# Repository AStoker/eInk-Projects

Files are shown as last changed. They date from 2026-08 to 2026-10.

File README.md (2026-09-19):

# eInk Projects

A 4.2" three-colour e-paper panel in a printed desk frame that shows today's
agenda, your photos, or a picture generated overnight.

| Where | What |
|---|---|
| [stand-4.2in/](stand-4.2in/) | The printed frame, the wiring, the power budget |
| [daily-dash/](daily-dash/) | ESPHome firmware for the panel |
| [eink-app/](eink-app/) | Home Assistant app that converts images for the panel |
| [IMAGE-PIPELINE.md](IMAGE-PIPELINE.md) | How a picture becomes ink: blob format, prompts, contracts |

This repo is also a **Home Assistant add-on repository** (`repository.yaml`),
so the app installs from the store rather than by copying files.

## Using it day to day

Everything is grouped under the **eInk Daily Dash** label in Home Assistant.

| Control | Does |
|---|---|
| `input_select.eink_daily_dash_mode` | **Dash** (agenda), **Photos**, or **AI** |
| `input_text.eink_daily_dash_theme` | Theme for the generated pictures — `fall`, `christmas`, blank for free choice |
| `input_boolean.eink_daily_dash_disable_deep_sleep` | Hold the panel awake so it can be flashed |
| `button…refresh_display` | Redraw now — only works while the panel is awake |
| `automation.eink_daily_dash_generate_ai_images` | The 3am job. Run manually to preview |

**To show your own photos:** drop them in `/media/eink/photos/` and switch the
mode to Photos. Subfolders are fine. The app picks them up within 20 seconds,
converts them, and the panel rotates one photo per wake. Nothing else to do —
no resizing, no naming convention, no restart.

**To change the generated pictures:** type a word into the theme box. That
night's set follows it.

## How the panel behaves

It wakes every 15 minutes, draws once, and sleeps — about 25 seconds awake,
because a full e-paper refresh takes 17 of them. Two consequences worth
knowing:

- **A button press only lands while it is awake.** Mode and theme changes take
  effect on the next wake, up to 15 minutes later. To make a change land now,
  turn the hold-awake toggle on first — then the panel is listening.
- **It only refreshes when the picture actually changed.** The panel asks the
  app for a short revision string first and skips the refresh if it matches.
  **Pressing Refresh Display overrides that**, as does changing the mode, so a
  deliberate request always redraws.

## Flashing

`daily-dash/example-device.yaml` is the device file for ESPHome Device Builder;
it pulls the firmware from this repo. See [daily-dash/](daily-dash/) for the
package layout and the two entry points.

The case has no opening for the driver board's USB-C, so **OTA is the only way
in once it is assembled**. Turn the hold-awake toggle on before flashing. A
cold boot also stays up for two minutes regardless, which is the way back in if
the toggle is unreachable.

## State of things

| Working | Not done |
|---|---|
| Agenda rendering, deep sleep, OTA window | Battery divider not fitted — GPIO 35 floats, HA shows ~0 V |
| Nightly generation, theming, photo drop | Low-voltage cutoff, deliberately, until the divider reads true |
| Blob format, converter, image server | The app has not yet run inside Home Assistant |

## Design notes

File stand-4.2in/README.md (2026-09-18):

# 4.2" e-Paper desk frame — minimal bezel, snap-out kickstand, battery inside

A slim desk frame for the **Waveshare 4.2inch e-Paper panel (B)** driven by the
**Waveshare e-Paper ESP32 Driver Board (Rev 3)**, with a LiPo and a power-path charger
inside, and a single kickstand leg on the back that folds flush and swings out onto a
positive mechanical stop. Portrait.

The panel is **bare glass and an FPC tail** — no PCB behind it. The tail leaves the centre of
the **RIGHT** side and makes a shallow S, out and up towards the **TOP**, before turning
inboard. It reaches the driver board's socket — but it has no slack, so it cannot survive the
cover being lifted off. A **Waveshare FPC adapter** is fitted as a service loop.

One parametric OpenSCAD file: `src/epaper_stand.scad`. Every dimension quoted here comes
out of it, and so does every drawing — `tools/mkdrawings.py` reads the model's own
parameter dump, so the sheets cannot drift from the STLs. **The renders are built from
`stl/*.stl` itself** (`tools/mkrenders.sh`), so what the pictures show is what the slicer
gets.

| | |
|---|---|
| Outer | 91.9 × 110.5 × 25.0 mm |
| Bezel | 13.45 mm short-axis sides, 11.55 mm long-axis ends |
| Panel white showing | 0.7 mm short axis, 1.3 mm long axis |
| Lean | 22.3°, 34.1 mm footprint |
| Interior | 81.6 × 92.5 × 21.0 mm, with 9 mm end walls |
| Fasteners | 4 × M2.5 countersunk into heat-set inserts, one near each corner |
| Print | 3 parts, ~112 g of filament; supports on the leg only |

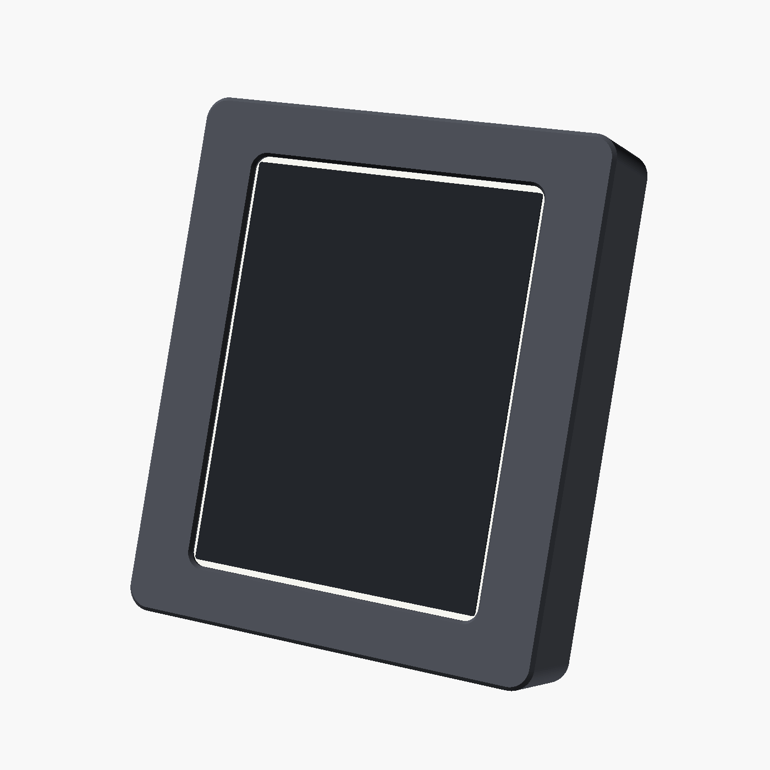
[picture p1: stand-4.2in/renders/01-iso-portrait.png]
Deployed
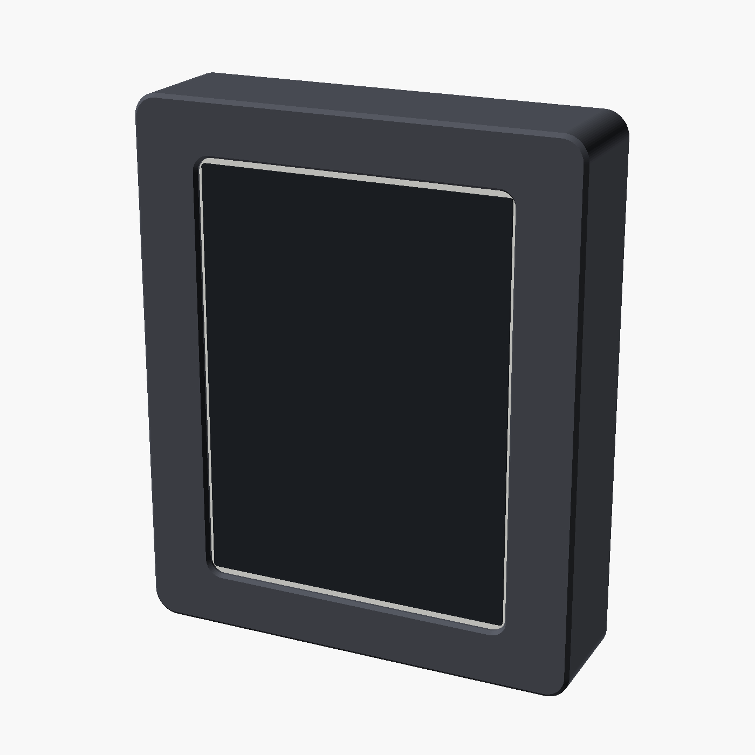
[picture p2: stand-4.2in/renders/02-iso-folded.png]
Folded
 

Sheet 1 — assembly and envelope

Open [`drawings/index.html`](drawings/index.html) for all eight sheets on one page,
[TODO.md](TODO.md) for what is still open, and [`fusion/README.md`](fusion/README.md) to
pick the model up in Autodesk Fusion.

---

## Names

Two dimensions got read as the wrong axis while this was being built, both times because
"width" and "height" swap over when the frame is turned. So: **never width/height for
anything belonging to the display.**

| Axis | Glass | Interior | Model | In portrait (the default) |
|---|---|---|---|---|
| **short axis** | 76 | 82.1 | X | horizontal |
| **long axis** | 90 | 80.9 | Z | vertical. **The ribbon leaves the glass on a long-axis edge, and runs along the long axis.** |
| **depth** | 1.05 | 21.0 | Y | 0 at the outer front face |

Depth is the axis that points *up* off the print bed, so "taller", "more room on top" and
"height off the glass" in slicer terms all mean **deeper** here.

### The four sides have names

Width/height are banned because they swap when the frame turns. So do "top" and "bottom"
unless you say which way up — so the datum is fixed once, here, and everything uses it:

**Hold the panel with the front face down, in portrait.** You are looking at the **rear
face**. Put 0,0 at the top-left, X increasing across, Y increasing down. Then:

| Side | Which edge | Length | Runs along |
|---|---|---|---|
| **TOP** | Y = 0, X sweeping across | 76 (glass) | the short axis |
| **BOTTOM** | Y = max, X sweeping across | 76 | the short axis |
| **LEFT** | X = 0, Y sweeping down | 90 | the long axis |
| **RIGHT** | X = max, Y sweeping down | 90 | the long axis — **the tail leaves this side** |

And the two faces are **front face** (the ink you look at) and **rear face** (the back, facing
you during assembly). Never "top face" for either.

### How those map into the model

The model does not use the build frame and is not going to be renamed, so here is the
mapping. It is worth reading once, because two separate bugs came out of getting it wrong:

| Build frame (front face down, 0,0 top-left) | Model |
|---|---|
| **TOP** | `+Z` end — `Z = 100.25` at the glass |
| **BOTTOM** | `−Z` end — `Z = 10.25` at the glass. **The kickstand folds down towards here**, foot tip at `Z = 3` |
| **LEFT** | `+X` side |
| **RIGHT** | `−X` side — the ribbon relief reaches `x = −44.95` |
| **front face** | `Y = 0` |
| **rear face** | `Y = 25` |
| X increasing (left → right) | `−X` direction |
| Y increasing (top → bottom) | `−Z` direction |

Two sign flips to keep hold of:

- **Build-Y and model-Z run opposite ways.** "18 mm down from the top" is `Z = 100.25 − 18`,
  not `Z = 18`.
- **Build-X and model-X also run opposite ways**, because looking at the *rear* face reverses
  the short axis. Derive it if you doubt it: looking along `−Y` with `+Z` up gives a view-right
  of `cross((0,−1,0),(0,0,1)) = (−1,0,0)`. That is why RIGHT is `−X`, and why the relief being
  at `x = −44.95` is correct rather than mirrored.

What fixes `−Z` as the BOTTOM, independently, is the kickstand: it pivots at `Z = 58` and its
foot folds *down* to `Z = 3`, and a stand's foot is at the bottom.

### The ribbon route

Front face down, portrait, so you are looking at the **rear face**. The tail leaves the
**CENTRE of the RIGHT side** — not an end — and makes a shallow S:

| Leg | Direction | Size | Parameter |
|---|---|---|---|
| 1 | straight out from the glass edge | 4 mm | `rib_out` |
| 2 | 90° turn towards the **TOP**, running parallel to the RIGHT edge | 9 mm wide × 20 mm long | `rib_band`, `rib_run` |
| 3 | 90° turn **away from the RIGHT side** — inboard, across the rear face | 10 mm | `rib_leg3` |

Leg 2 is the whole reason the relief is a slot rather than a local pocket at the exit: the
ribbon spends 20 mm travelling *parallel* to the RIGHT edge before it turns inboard. Leg 2 is
9 mm wide but only reaches 4 mm outboard of the glass — the other 5 mm of its width lies
*behind* the glass, which is open interior, so the frame only has to clear 4 mm.

The three relief sizes are deliberately *not* called width/height/depth:

| | Parameter | Now | Meaning |
|---|---|---|---|
| **out** | `rib_clr` | 3.0 | outboard from the pocket edge, along the short axis |
| **deep** | `rib_dep` | 3.0 | past the glass back face, along depth — so the fold has somewhere to go |
| **long** | `rib_w` | 49.0 | along the RIGHT edge, on the long axis |

**`rib_w` and `rib_off` are derived from the route now, not typed in.** `rib_w` is
`rib_run + rib_band + 2 × rib_marg` and `rib_off` puts the slot's near edge half a band below
the exit, so the slot straddles the exit and covers the run to the TOP. They come out at 33
long, **30.5 up from the BOTTOM, 10.5 short of the TOP** — and they cannot drift from the
route any more, which is how they went wrong twice:

- `rib_off = 15` put the slot at the **BOTTOM**, under a source comment insisting the model's
  −Z was the top and warning against "fixing" it. It was the reversed reading it warned about.
- `rib_off = 35` then put the slot 15 short of the **TOP**, from reading "the ribbon is towards
  the top" as the exit position. The exit is at the **centre**; it is the *run* that goes
  towards the top. It is 30.5 now, and derived rather than typed.

**One clearance is 0.25 mm short.** Leg 1 needs 4 mm out from the glass edge; the relief gives
3.75 (`rib_clr` 3.0 from the pocket edge, plus 0.75 of pocket clearance). `rib_clr = 3.25`
would fix it and grows the frame 0.5 mm on the short axis. The stand no longer rides on the
frame's width, so the stance does not move with it, but the frame does. The echo prints the
shortfall on every run.

### The tail reaches the driver — but it cannot cross the split

The driver board faces **down**, so its socket edge is the one nearest the display, and the
tail can meet it. Leg 3 runs **10 mm** inboard, ending between x −35.2 and −26.2.

Which way round the board is mounted decides whether it fits:

| Socket 12.5 mm from… | Board spans | |
|---|---|---|
| the **BOTTOM** end | z 62.75 … 111.0 | overruns the interior top by 9.5 mm |
| the **TOP** end — hangs downward from the socket | z 39.5 … 87.75 | **fits** (`fpc_end = "top"`) |

So a direct plug-in works geometrically. **The reason it still is not enough is service.**

The glass is on the **frame**. The driver is on the **cover**. Anything joining them crosses
the split, and the panel's tail cannot:

| | |
|---|---|
| Tail length | 18 mm, with no slack designed in |
| What its 180° fold gives back when it straightens | (π−2) × `rib_dep` = **3.4 mm** |
| Lift needed to get a fingernail on a ZIF lever | ~25 mm |
| Shortfall | **21.6 mm** |

Lift the cover and you are pulling on the glass. So the **adapter is a service loop, not a
reach fix**: the short tail plugs into it on the panel side, and a longer FPC crosses the
split with enough slack to open the case.

### Where the service loop goes

Two placements were costed and both fail, which is worth recording because the answer is
neither of them:

- **In front of the driver.** Stacks 5 mm onto 16 against the 17.45 mm the driver column has —
  3.55 short, and the driver's own USB-C shell and WROOM module already take most of what is
  left there. It would cost `depth` 25 → 28.55, or low-profile headers (`hdr_h` 8.5 → 5.5 buys
  back 3.0).
- **On the carrier board.** Driver 48.25 + adapter 32 = 80.25 against 70, and overhanging fails
  too because the adapter's corner holes are 28 apart, so the far pair lands off the board.

Mounting the driver on the **frame** instead, so nothing crosses the split at all, does not
work either: the glass drops in through the interior and needs the full 90 mm clear, so
anything standing off the frame's ledge blocks it — the same reason there are no corner posts.

**The adapter is taped to the back of the glass.** That is what makes it fit, and it is also
the right side of the split — taped to the glass it stays with the **frame**, so the panel's
short stiff tail never crosses the joint and only the long FPC does.

| | |
|---|---|
| Outline | 18 × 32 × **5 mm** (depth with both connectors, confirmed) |
| Where | against the glass's back face, x −40.45 … −22.45, z 65.75 … 97.75 |
| Depth there | glass back 2.65 to the carrier's face 18.5 = **15.85 mm**, so it clears by 10.85 |
| Clear of the driver's parts by | 2.0 mm (`adapt_gap`; 1.0 still caught them by 0.2) |
| Leg 3 | turns at z 75.25 and runs **10 mm** inboard, ending between x −35.2 and −26.2 — **lands on the adapter** |
| Holding force | 18 × 32 = 5.8 cm² of foam tape ≈ 46 N in shear against a 0.02 N part |

It overlaps the carrier by 18.75 mm **in plan view**, and that is not a clash — they are 10.85 mm
apart in depth. Reading that plan-view overlap as a conflict is what made the adapter look
homeless for so long, and it was never real.

Two things moved to make room, both small: the **top glass-retention rib** shifted toward +X
(`pad_off1` 12.0 → 7.8, so it spans x −21.0 … −1.0 instead of −25.2 … −5.2, still well inside
the glass's dead border), and the adapter sits 2 mm above the driver's tall parts.

The one real risk is **peel, not shear**: a 24-pin FPC pushing perpendicular can lift a corner.
Route the tail so its spring-back loads the tape in shear, and use foam rather than a thin
film so it can absorb the bend.

**Oversize is free here.** The hollow is only ever a problem when it is too *small*, so
`rib_marg` is set generously (10) rather than to the route. The hollow is **49 mm** — 14.5 mm
below the exit and 34.5 above — which covers leg 2 running anywhere from nothing to 34 mm, and
so covers both the 18 mm and the 24 mm readings of the tail length. That takes the
disagreement between them off the critical path.

**What caps its length is the corner screws, not the route.** The inserts at z 14.5 and 96
reach x −38.65, which overlaps the hollow's x −44.95 … −41.95 by 3.3 mm — so the hollow has to
stop short of them. It ends at z 89.75 against a bore starting at 94.2: **4.45 mm of headroom.**
The other cost of length is the 1 mm outer wall outboard of it, now 49 mm long. The
`RIBBON HOLLOW HEADROOM` echo prints both on every run, so it cannot quietly grow into a screw.

**Leg 3 only has to land on the adapter, not hit a socket.** The tail folds over onto it, and
the cable on from the adapter to the driver is routed by hand — so nothing downstream of the
adapter is constrained by geometry. That is what takes the whole layout off the critical path.

**One measurement still disagrees:** the route needs at least 4 + 20 = **24 mm** of developed
tail before leg 3 starts, against the **18 mm** measured flat. Whichever is right decides
whether leg 2 really runs 20 mm, and `rib_w` / `rib_off` are derived from it — so the ribbon
hollow moves with it.

### The three nested recesses

Front to back. Not interchangeable, and each has its own clearances:

| Name | What it holds | Size | Parameters |
|---|---|---|---|
| **window** | nothing — it's the through-opening the ink is seen through | 65.0 × 87.4 | `win_*` |
| **glass pocket** | the glass, in a shallow step | 77.5 × 91.5 × 1.26 | `pan_*` |
| **interior** | the electronics — driver board, cell, charger | 82.1 × 80.9 | `cav_*` |

**The interior is sized by two things: the electronics, and the glass getting in.** The
glass has no way into its pocket except from the back, through the interior — the front lip
is smaller than the glass. So the interior opening has to clear the glass on every side:

```
GLASS GOES IN: interior x -42.45 to 39.15, z 9 to 101.5
             | glass    x -42.45 to 36.05, z 10.25 to 100.25
             -> clears on every side, drops straight in
```

Note that it checks **extents, not sizes**. The glass is offset 3.2 mm to centre the ink, so
an interior that is wide *enough* can still be in the wrong place — comparing sizes left it
0.4 mm short on the −X side, which is a glass that does not go in.

### Why there are no screw posts inside the interior

Corner posts would be the obvious way to get four corner screws without growing the frame,
and they do not work. A post at each corner leaves a 74.5 mm gap for a 90 mm glass, so the
glass would have to go in at an angle — and the arithmetic says it cannot:

| To shorten the glass's span to | you must tilt | which stands it |
|---|---|---|
| 85 mm | 19.2° | 29.6 mm tall |
| 83 mm | 22.7° | 34.8 mm tall |
| 81 mm | 25.8° | 39.2 mm tall |

The interior is **20.9 mm deep**. The glass is flat long before its far end is low enough to
clear anything, and flat it needs a post-free path the full 90 mm. Working it the other way:
with 9 mm posts the glass is blocked by 5.9–7.0 mm no matter how deep the posts start, and
only a **3 mm** post ever clears — which will not hold an insert.

So the screws go in the end walls, and the end wall has to be thick enough to take one:
rear chamfer + margin + head + margin. That is what sets the frame's long axis now.

| Insert | Head | End wall | Frame length | End bezel |
|---|---|---|---|---|
| M2 | 4.0 | 8.0 | 108.5 | 10.55 |
| **M2.5** | **5.0** | **9.0** | **110.5** | **11.55** |
| M3 | 6.0 | 10.0 | 112.5 | 12.55 |

M2.5 is the default: 2.1 mm of extra length against today, and four screws that go where
they are wanted. `insert_size` moves the whole frame with it.

### Vocabulary

- **bezel** — the visible plastic between the window edge and the outer edge (13.45 on the
  short-axis sides, 10.5 on the long-axis ends). Never the pocket. Also not a *bevel* — a
  bevel is an angled edge, which here is a **chamfer** (`front_chf`, `win_chf`, `rear_chf`).
- **clearance** / **margin** — the gap between a part and the recess holding it. Always
  quoted as the **total across an axis**, not per side: "margin 1.5 on the short axis" is
  0.75 a side.
- **relief** — material taken away at a **corner**, so a sharp-cornered part can seat in a
  printed corner that carries a nozzle fillet. Always centred *on* the corner; that is the
  function, so it cannot be moved inboard. One is fitted: **pocket relief** (`pan_rel` = 1.4,
  at the glass pocket corners). Because it is centred on the corner it bulges 1.4 mm
  *outboard* of the pocket — further out than the interior reaches on three sides — so the
  interior wall used to **overhang it by 0.9 mm**. The same four circles are now carried up
  through the wall as well (see `cavity()`), so the opening holds at x −43.32 from the pocket
  right through to the rear face instead of stepping back in. It costs nothing dimensionally:
  2.63 mm of wall is still left outboard of the worst corner.
- **ribbon relief** — the slot described above.
- **white show** — `white_show_short` / `white_show_long`, the strip of the panel's own white
  border left visible inside the window on purpose. **One per axis** (0.7 short, 1.3 long),
  because the window is specified on the short axis and one shared value cannot do both.
- **parts** — **frame** (front shell), **cover** (back), **leg** (kickstand), and the
  **bezel test tile** (front-face-only print for checking fit).
- **tape pad** — `tape_*`, a shallow recess in the **ledge behind the glass** where tape holds
  the glass down from the rear. Two of them, one at each long-axis end. Not visible from the
  front.

### How the glass is held

A printed 91.0 pocket measured short on the long axis, so the pocket is **77.5 × 91.5** —
1.5 mm of total margin on *both* axes, sized for print variance rather than for a press
fit. The front lip stops it coming forward. Behind it the interior is open, because it has
to be, so something has to press it back against that lip: **two ribs on the cover**, one at
each long-axis end, over the glass's dead border — 36 mm and 20 mm wide × 3.5 mm, standing
the full 21 mm from the cover face to just behind the glass. Foam tape on their faces takes
up the tolerance stack.

The top rib is the short one because the charger runs up that side of the interior.

---

## Power

One cell, one charger, one conversion. USB-C in at the back face, the charger's power-path
output straight to the driver board's 5V pin, which Waveshare specify as a **3.6–5.5 V
input** — a 1S cell drives it directly.

Sheet 8 — power wiring

- **Adafruit bq25185** (#6091, $6.95): USB-C in, JST battery, JST load out regulated to
  ≤4.5 V, real power path so the board runs from USB while the cell charges instead of
  cycling it. Charge current is a solder jumper — **set 1 A**, which is 0.5C for this cell.
  Adafruit's own two pages disagree on what it ships at (product page says 1 A, the pinout
  guide says 500 mA), so check the board.
- The board's 5V pin is an input only: no charge circuit, no battery connector, no charge
  LED. Running from a cell and refilling that cell are two separate jobs, which is why the
  charger is in the build.
- **Charge port is on the back face**, not the charger's own USB-C. A snap-in panel-mount
  pigtail with the 5.1 kΩ CC pulldowns sits in the back face at **x −5, z 92** — immediately
  left of the charger, so the two wires to its **VBUS** and **GND** pads run about 4 mm
  instead of crossing the whole interior. Charge only, no data — which is all this needs.
- **Battery divider:** two 100 kΩ from the cell to **GPIO 35**, wired as below. The
  firmware reads it on every wake and reports the voltage to Home Assistant.

### Wiring the battery sense

The ESP32 cannot read the cell directly — a full 1S pouch is 4.2 V and the ADC tops out
around 3.1 V — so the cell is halved by a divider first.

```
  cell +  (JST B+, red)
     |
    [R1] 100 kΩ
     |
     +-------------------> GPIO 35   (ADC1_CH7, the divider tap)
     |
    [R2] 100 kΩ
     |
  cell -  (JST B−, black, common with the driver board's GND)
```

Both resistors are 100 kΩ, so the tap sits at exactly half the cell: 4.2 V reads 2.10 V,
3.6 V reads 1.80 V. The firmware's `multiply: 2.0` filter puts it back. Equal resistors
are the whole trick — change one and change `batt_divider` in the YAML to match.

| Why this value | |
|---|---|
| **100 kΩ + 100 kΩ** | 200 kΩ across the cell draws 21 µA, about 1% of the board's 2 mA idle. Ten times smaller wastes real runtime; ten times larger and the ADC's own input impedance starts to pull the reading down |
| **GPIO 35** | ADC1. **ADC2 cannot be read at all while WiFi is on**, which rules out the entire 0/2/4/12–15/25–27 group. GPIO 35 is also input-only, so it can never be driven high into the divider by accident |
| **not GPIO 32/33** | Also ADC1 and equally valid, but they are the two RTC-capable pins the frame's button cutouts are waiting on — see the buttons section. GPIO 35 leaves both free |
| **not GPIO 34/36/39** | Fine electrically. GPIO 35 is simply the one the firmware is set to; change `batt_adc_pin` if the header layout makes another easier to reach |

Tie the divider's bottom leg to the **driver board's** ground, not just the cell's — the
ADC measures against the ESP32's own ground reference, and a divider referenced somewhere
else reads whatever the difference between them happens to be. They are the same net once
the cell is plugged in through the charger, so this is about which point you land the
wire on, not about adding a connection.

Nothing is fitted yet, so **GPIO 35 currently floats and Home Assistant shows a near-zero
voltage** — that is the reading for "not wired", not a flat cell.

Still to do once it is fitted: the low-voltage cutoff. The intent is that below ~3.6 V the
firmware calls `esp_deep_sleep_start()` with no timer and stays there — the board browns
out at 3.6 V on its own, but a brownout loop drags the cell down to its protection cut,
and deep discharge is what kills LiPo cells. That path is deliberately **not** in the
firmware yet: with no divider fitted the floating pin reads near zero, which looks
identical to a flat cell, and a board that sleeps with no wake source inside a sealed case
is unrecoverable. Wire the divider, confirm the voltage reads true, then add the cutoff.

### One opening in the whole assembly

The **charge port in the back plate is the only hole in the finished case.** The driver
board's own USB-C — which is for *flashing*, not power — used to sit against the top wall
behind a blind pocket. Now that the board is stood on the −X side to meet the ribbon, its
jack ends up in the middle of the interior instead, so there is nothing to cut and nothing
to seal: the pocket is skipped entirely and the top wall is solid material.

⚠ **Flash the ESP32 before final assembly**, and leave OTA working. With the port closed
there is no wired access to the driver board once the cover is on. Set `flash_port = true`
to cut the opening back through.

### Runtime

The driver board sets it: Waveshare rate it at `<2 mA` idle, and only with the **DIP switch
set so the USB-UART is unpowered** — left powered, a reviewer measured 10–13 mA in "deep
sleep". So: **switch on to program, off to run.** (On the Rev 3 schematic that chip is a
**CH343**, not the CP2102 quoted on the older product page; SW1 gates its supply from
VBUS.)

The same schematic shows **GPIO 4 driving an S8050 that gates the panel's supply rail**
(VDD5V → VDD5V′, feeding the EPD 3.3 V regulator). That is a real power saving — the panel
rail can be switched off in sleep — and it means **GPIO 4 is not free for anything else.**

At 2 mA and ~49 mAh/day, against the 3.6 V floor (which leaves about 85% of the cell's
2000 mAh usable), runtime is **roughly five weeks** — about 35 days on battery, ~41 days
standby, ~33 days with an hourly refresh. About 95% of that budget is the board sitting
idle; a few refreshes a day cost barely 1 mAh between them. Refresh as often as you like,
it is not what empties the cell.

`<2 mA` is a spec, not this board — put a meter in series with the battery lead and read
the real number. If there is a power LED, cutting it is often worth 1–2 mA on its own.

### The cell

A salvaged 1S pouch, **2000 mAh, 694449, 44 × 49 × 6.9 mm**, three wires, all three
checked on this pack:

| Wire | Is | Goes to |
|---|---|---|
| red | **positive** (verified against black) | JST B+ |
| black | **negative** | JST B− |
| yellow | the other leg of a **10 kΩ NTC** (measured yellow→black at room temperature; its common leg is tied to black) | the charger's **TH** pad |

So the thermistor gets used: **cut the TH jumper** on the #6091 (it ships jumpered, which
disables the function) and wire yellow to the pad. The charger then refuses to charge
outside roughly 0–45 °C instead of trusting a salvaged pouch to behave.

The pack also carries **its own protection PCB** under the tape at the tab end, so it has
overcurrent, overdischarge and short protection independent of the charger.

## Buttons

Not fitted, but the frame is ready. The display uses **GPIO 13 (CLK), 14 (DIN), 15 (CS),
25 (BUSY), 26 (RST), 27 (DC)**; everything else on the headers is yours. For buttons that
also wake the ESP32 from deep sleep you need RTC-capable pins — **GPIO 32/33 are the
cleanest** if the headers bring them out. **Not GPIO 4** — on this board it gates the
panel's supply rail. Keep off 0, 2, 12 and 15 as well: they are strapping pins, and a
button held at reset changes boot behaviour.

To add them later: set `btn_n = 3` in the SCAD file and re-export the frame. That cuts
three Ø4.2 plunger holes in the +X wall (9.4 mm thick, the only wall with real meat in
it), 12 mm apart, for switches mounted on a strip inside. There is no room for front
buttons — the bezel is 10.5 mm and the module's PCB is directly behind it.

---

## What goes where

Interior is 82.1 × 80.9 mm in two columns: the driver board against the −X wall — the wall
the ribbon arrives at — and the cell with the charger above it on the +X side.

Sheet 2 — internal layout

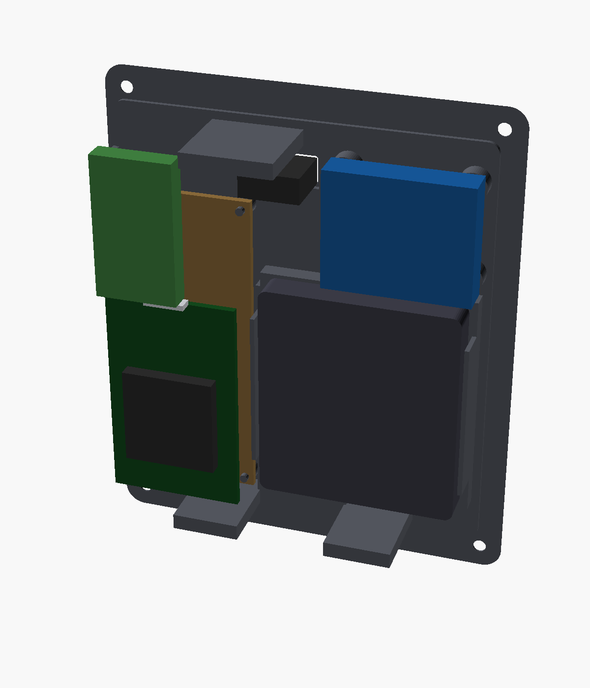
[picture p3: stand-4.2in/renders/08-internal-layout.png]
Boards and cell in the cover
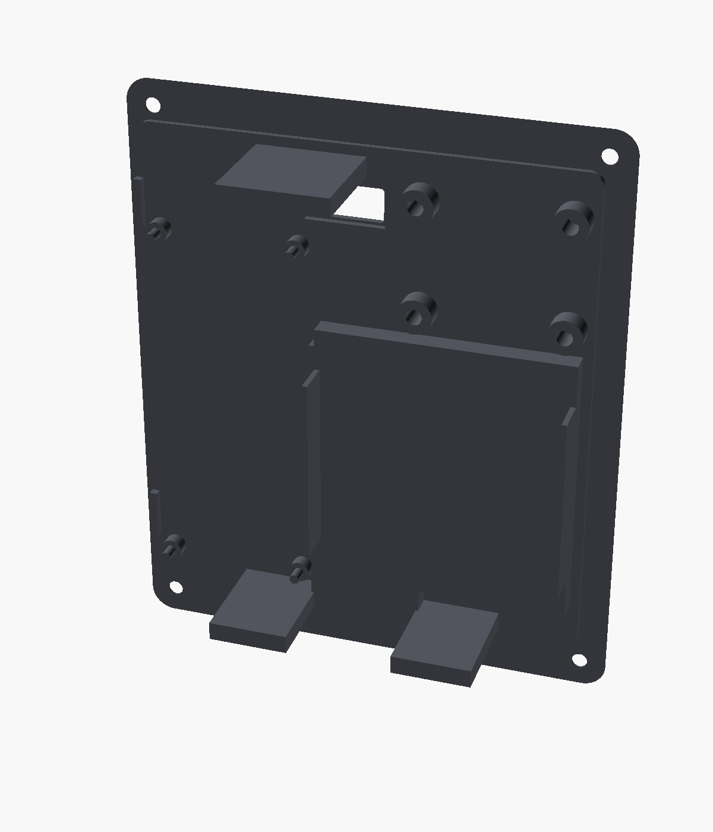
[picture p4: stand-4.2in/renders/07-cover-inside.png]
Cover inner face
 

| | Size | Where |
|---|---|---|
| Carrier perfboard | 30 × 70 | −X column, z 14.5…84.5, on four pads that hold it 2.5 mm off the cover |
| Driver board | 29.46 × 48.25 | plugged into the carrier, **z 15.5…63.75 — low**, because the adapter frees it from the ribbon |
| 24-pin FPC socket | 16 wide, 12.5 from the board's near end | on the board's −X edge, centred at z 28.0 |
| FPC adapter | 18 × 32 × ~5 | at leg 3's turn, centred z 75.25 — **overlaps the carrier, no home yet, and may not be needed** |
| Cell | 44 × 49 × 6.9 | +X column, low |
| bq25185 charger | 32 × 26.3 × 7.2 | +X column, above the cell |
| USB-C pigtail | **14 × 4.5 body** (measured), 10 deep | snapped into the back cover, low and off the leg's centreline. The printed opening is 14.3 × 5.0 — clearance per side, because a hole exactly the size of the part will not take it |

**The board used to be positioned by the ribbon, and is not any more.** It was placed so its
socket landed opposite the middle of the ribbon slot. The tail's own S means the connector has
to meet leg 3, at z 75.25 — and a board with its socket 12.5 from the *bottom* end then runs
9.5 mm off the top of the interior. With the adapter fitted the driver goes **low on the
carrier** (z 15.5…63.75) where it fits. Turned end-for-end it would fit at z 39.5…87.75 with
no adapter at all — see above.

### The driver board plugs into a carrier, it is not held by the case

The Waveshare board has **no mounting holes** — but it does have its two 19-pin male headers
soldered on. So it plugs into female headers on a **carrier perfboard**, and the carrier is
what the case holds, on four pads. Nothing printed touches the driver board itself.

A 30 × 70 cut of double-sided 0.1″ prototype board does it. The driver takes 48.25 of the
70, which leaves **about 14 mm × 30 of spare board below it** — that is where the battery
divider goes, so there is no separate scrap of perfboard any more.

The stack is the number to watch: `carrier_lift` 2.5 + carrier 1.6 + female header 8.5 +
driver PCB 1.6 leaves **5.75 mm** in front of the driver for parts that stand about 4.4 proud.
That is 1.35 mm of margin on two assumptions (`hdr_h`, `drv_env`), and low-profile sockets buy
3 mm of it back.

**The headers are soldered from the far side**, so clipped pin tails and their solder fillets
stand proud of the face that lands on the cover. `carrier_lift` is the air left under the
board for them: each corner pad holds the board **2.5 mm off the register face**, and the
locating peg carries on through the hole from the top of that pad. It is spent out of the
driver column's depth budget, which is why that budget is stated below rather than assumed.

### Why not the half-size Perma-Proto

It fits the interior (81.3 × 50.8) and both boards do fit on it — the driver turned 90° is
50 along its length, the charger 26.3, against 81.3 available. What it leaves for the cell
is a 28.7 mm-wide column and a 79.5 × 22.7 strip, and the cell is 44 × 49. So it only works
with a much narrower cell (roughly 28 × 90 × 7, ~1500–1800 mAh) or a bigger frame.

The quarter-size board is gone too, for the same reason the corners needed: it was the
widest thing in the box. The charger now sits on four screw posts of its own.

### The ribbon relief sets the frame width

The ribbon slot still reaches further out than the interior does, so the frame's short axis
is set by the notch rather than by the electronics:

```
SHORT AXIS driven by: THE RIBBON RELIEF  (cavity needs 44.03, ribbon needs 45.95)
OUTER: short axis 91.9 | long axis 108.4 | depth 25
```

The model grows `W` automatically to keep `wall_rib = 1.0` mm of material outboard of the
notch, so it is always valid — but it costs **3.60 mm of width** over what the electronics
need, and put the side bezels at 13.45 mm. The notch sits just outboard of the *pocket*, so
widening `pan_clr_w` pushes it out and the frame grows with it; that is why the 0.75 mm
pocket clearance cost 0.5 mm of overall width.

One measurement gets most of it back: how far the glass sits from the PCB edge on the
ribbon side. The PCB is 78.5 wide and the glass is 76, so there is 2.5 mm to distribute.

| `pan_off_x` | Frame width | Side bezel | Short axis driven by |
|---|---|---|---|
| 0 — glass centred (assumed) | **91.9** | 13.45 | the ribbon relief, needing 45.95 |
| 0.625 | 90.65 | 12.83 | the ribbon relief, needing 45.33 |
| 0.8 | 90.3 | 12.65 | crossover — ribbon and cavity both need 45.15 |
| 1.25 and beyond | **90.3** | 12.65 | the PCB cavity. Nothing past 0.8 buys any width |

So the whole prize is **1.6 mm of width and 0.8 mm of side bezel**, and it is all collected
by the first 0.8 mm. Measure the gap between glass edge and PCB edge on *each* side of the
ribbon axis, set `pan_off_x` to half the difference, and re-export. It is on the
[TODO](TODO.md).

### Depth is the tight axis

Sheet 3 — depth stack-up

With no PCB in front of it, the interior starts right behind the glass and the budget got
easier: **19.95 mm** deep off the recess band, **16.05 mm** across it, and **9.15 mm** clear in
front of the cell. The cell needs 6.9 of that 9.15.

Nothing is plugged into the back of the panel — it is bare glass and a tail — so the stack
that has to be watched is the **driver board on its carrier**, and that has now been
measured as a whole rather than guessed in three parts:

| | |
|---|---|
| Driver board + female sockets + carrier PCB | **16.0 mm**, measured, back face to tallest point |
| Register face to the glass plane | **19.95 mm** |
| less `carrier_lift`, the air under the board for its solder joints | −2.5 mm |
| Room in the driver column | **17.45 mm** |
| Spare | **1.45 mm** |

`drv_stack = 16.0` is the number that decides fit, and it supersedes adding up `drv_env`,
`hdr_h` and `carrier_t` — those still exist for the features that need them individually, but
their sum is no longer the test.

The carrier datums to the **register face** at depth 22.6 — `cov_in` (23.6) is the skin datum,
but `cover()` lays a register prism 1.0 mm proud of it across the whole cavity, and that is the
face the pads stand on, putting the board itself at 20.1. It clears the stand's recess entirely: the recess is a
16 mm band on the centreline and the carrier sits at x −41.45…−11.45. Only the **cell** crosses
the band, and it rides a platform level with the back of the recess floor at 18.7 — worth
3.9 mm to everything that misses it.

### Mounting

- **Carrier board** — four **Ø1.85 pegs on Ø4.0 pads 2.5 mm tall**, at the board's own hole
  pattern: four Ø2.0 holes at **26 × 66 centres** (24 × 64 edge to edge), 2.0 mm in from each
  edge of the 30 × 70 board. The pad carries the board and leaves `carrier_lift` = 2.5 mm of
  air under it for the header solder joints; the peg carries on through the hole and locates
  it. The first header pin is only 2.0 mm from each hole, so **nothing on a pad or a peg may
  exceed 4.0 mm across** — which is why they are pegs and not screw bosses, and why the pad is
  4.0 and not wider.
  `cover_board` reports 16.70 mm³ here by design: `mock_board` is a plain slab with no holes in
  it, so the pegs necessarily pass through it. Watch the number — anything above 16.70 is
  something else touching the boards.
- **Charger** — four **Ø6.5 screw posts** standing 3.8 mm off the register face, each bored
  Ø2.9 × 5.0 for an **M2 heat-set insert** (3.2 × 4.0, plus 1.0 of relief for the plastic it
  displaces). The bore is **blind**: it reaches depth 23.8 against a back face at 25.0, so
  1.2 mm of skin is left and the back face carries no opening for the charger. The post height
  is derived from the insert and that skin rather than chosen — `chg_back` follows from it, and
  the board ends up at depth 18.8 with 8.95 mm clear in front of it.
  **The hole centres are 26.67 × 20.32**, measured off Adafruit's own solid model
  ([`fusion/vendor/adafruit-6091-bq25185-charger.step`](fusion/vendor/)): four Ø2.5 holes
  0.1 in in from each edge of a **31.75 × 25.40 mm PCB**, so the centres span 1.05 × 0.80 in.
  `chg_w` / `chg_h` stay the 32 × 26.3 **product envelope** — the USB-C jack overhangs the
  board — and the posts are centred on that envelope, which is why the spacing is measured
  rather than derived from it.
- **Driver board** — plugs into female headers on the carrier perfboard; the case holds the
  carrier, not the board. (`drv_rail` still exists for the no-carrier fallback.)
- **FPC adapter** — **foam double-sided tape, onto the back of the glass.** The case owes it
  nothing: no bosses, no screws, no pocket. Its four corner holes go unused. Taped there it
  stays with the *frame*, which is what keeps the panel's short stiff tail out of the joint.
- **Cell** — drops into a fenced pocket on a flat platform (the platform exists so the
  cell doesn't straddle the step where the stand pocket bulges into the interior).
  Foam tape holds it.
- **Panel** — bezel lip in front, 5.3 mm of solid frame behind each end. Tape in the
  recesses if you want it; nothing else is needed.

### Fridge magnets

Two **Ø8 × 2 mm disc magnets**, glued flat **onto** the back face, so the display can
hang on a fridge door instead of standing on its leg. The leg is unaffected and still works.

**They sit on the surface because the case already stands 2 mm off the door.** The USB-C
pigtail's flange is 2.00 mm proud of the back face, and it is the rearmost thing on the case,
so the door is held that far away wherever the discs go. A disc glued on the surface is
**2 mm thick and therefore exactly as proud as the flange**: it reaches the steel while the
flange rests against it. `mag_fit = false` is what leaves the face flat for them — set it
`true` to cut the sunk pockets and their bosses back in.

**A magnet is safe next to everything in this build but one thing, and that one thing is half
the placement rule.**

| | |
|---|---|
| The **e-paper panel** | Unaffected. Electrophoretic: an *electric* field between the electrodes moves the pigment. Magnetic sleep covers have sat against e-reader panels for over a decade |
| The **cell** | Unaffected. Neither pouch chemistry nor its protection PCB is magnetically sensitive. Pouch cells are damaged by puncture and heat, not fields |
| The **ESP32**, logic and RF | Unaffected by the field |
| **Inductors** — the exception | A strong field biases a ferrite core toward saturation, dropping its inductance and raising ripple. The only inductors here are on the driver board's panel-rail DC-DC |

#### The pair is mirrored about the centreline, and that is the other half

A pair offset to one side hangs the display crooked: the weight acts through the centre of mass,
which is on the centreline, and the magnets hold somewhere else, so the difference is a couple
the friction has to carry. **Equal x either side puts the pair's centroid at x 0**, under the
centre of mass, and the couple goes to zero.

**The two z's are not equal, and cannot be.** The −X half of the cover is driver carrier from
z 14.5 to 84.5, held only `carrier_lift` = 2.5 mm off the face — and that gap is not free, it
belongs to the header solder joints. The first free ground on that side is *above* the carrier.
So:

| | |
|---|---|
| **+X** | x +27.6, **z 83.65 — over the charger** |
| **−X** | x −27.6, **z 92.1 — over the carrier's top end** |
| Centroid | **x 0** — which is the number that matters |

Both positions are still derived and still echoed on every run, under `FRIDGE MAGNETS` — they
are the marks to glue to. `mag_x` comes off the top glass rib rather than being typed: the −X
position has to sit outboard of it, because with `mag_fit = true` that rib runs full depth to
the skin and a pocket there would break into it. Mirrored, the +X one lands between the
charger's post columns on its own.

#### How it hangs

The two discs and the pigtail flange are the only things proud of the back face, all three of
them by 2 mm, and all three sit in the top third of the case. The centre of mass is below them
and about 14 mm out from the door, so its moment about the contact line rolls the **bottom** of
the case in against the door. It hangs on three points at the top and leans on its bottom edge,
which is the favourable way round: that lean carries the tipping moment, and the discs are left
holding shear.

**Will it hold?** The assembly is about **194 g**, and the magnets work in **shear**, not in
tension — which is the number people get wrong. Two Ø8 × 2 N42 discs pull ~1.05 kgf each on
thick flat steel. Glued on the surface they make direct contact, so there is no standoff to
derate for; take µ ≈ 0.3 against a painted door and the shear capacity is **~6.2 N against
1.9 N hanging — about 3.3× margin.**

Two things will eat that, and neither is in the model's gift:

- **Many "stainless" fridge doors are not magnetic** (austenitic stainless). Test the door with
  any fridge magnet before gluing two on.
- **A thin door skin, and paint or laminate on it,** both derate the pull — a thin skin can
  halve it.

And one non-magnetic consequence worth knowing: **a steel door directly behind the PCB antenna
will detune and shield it**, so expect shorter WiFi range on the fridge than on a desk. That is
the real cost of fridge-mounting this, not anything the magnets do.

### Ports

| Port | Where | Purpose |
|---|---|---|
| USB-C pigtail | **back face**, 22 mm off centre, 12.5 mm up | Charging and running from the wall. Wired to the charger's VBUS + GND |
| USB-C (Waveshare) | on the driver board, mid-interior | Flashing, **before assembly**. Switch on to program, off to run |

The pigtail has its own snap-in catch, so the case owes it nothing but a **precise
rectangular hole and clear air behind it**: **14.3 × 5.0 for the measured 14 × 4.5 body**,
with 19.95 mm of interior behind it against the 10 mm the body
needs. No printed rails, no breakout board, no guide posts. A relief box `snap_d` deep follows
`ucb_x` / `ucb_z` automatically, so anything printed in the cover that would stray into the
pigtail's path is cut back without being asked.

**Measure the part before printing.** A snap fit lives or dies on a tenth of a millimetre,
and `snap_w` / `snap_h` / `snap_c` / `snap_ch` are the numbers that decide it.

**The two axes get different clearances.** `snap_c` = 0.15 a side across the **width**, `snap_ch`
= 0.25 a side across the **height** — 14.3 × 5.0 rather than 14.3 × 4.8. The height is the tight
axis: it is the small dimension, so it is the one a printed opening loses most of to its first
perimeter and to elephant's foot, and it is the one the body has to pass edge-on. The width has
slack to spare, and widening it is what would let the part rock in its hole. If 5.0 still fights
going in, `snap_ch` = 0.35 gives 5.2 and nothing else moves.

**Where it sits is a structural decision, not a routing one.** Openings in the back face must
not crowd each other: a narrow rib between two of them is what cracks. Low down, the port
shared an 8 mm band with the stand recess and its finger notches and left a **4.35 mm rib**
between two openings. At x −5, z 92 the nearest opening is **26.1 mm** away, and it lands in
the one large region of the interior nothing else was using — 48 × 16 mm above the driver
carrier and left of the charger.

`PORT CLEARANCES` echoes that distance to the stand recess, its finger notches and the nearest
corner screw on every run, so crowding shows up as a number rather than on a print. Under 4 mm
it fails outright; 4–8 mm it warns.

The cable therefore exits near the **top** of the back face. With the frame leaning back 22.3°
it runs up and away from the desk, and it is clear of the FPC adapter (x −40.45 … −22.45) and
of the glass retention rib above it by 2.2 mm.

---

## The kickstand

Sheet 7 — stand kinematics

Sheet 6 — leg and pivot

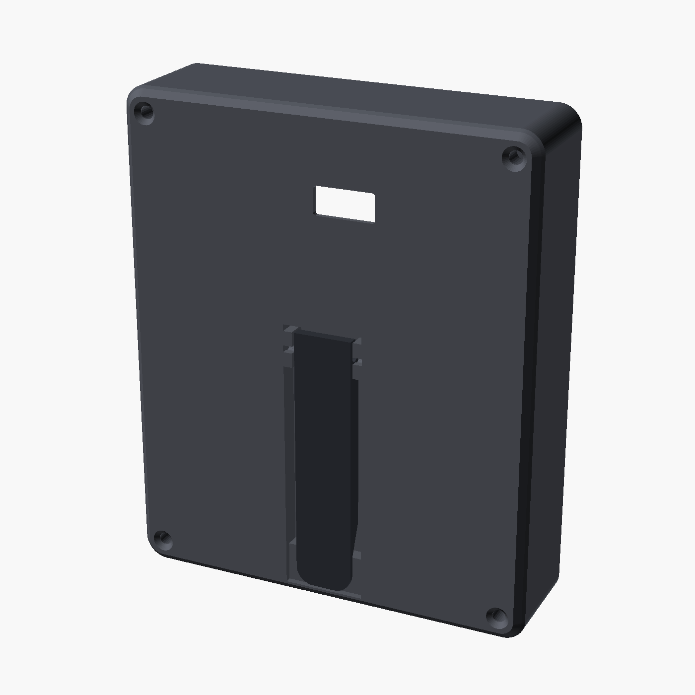
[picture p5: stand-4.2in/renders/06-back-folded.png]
Leg folded
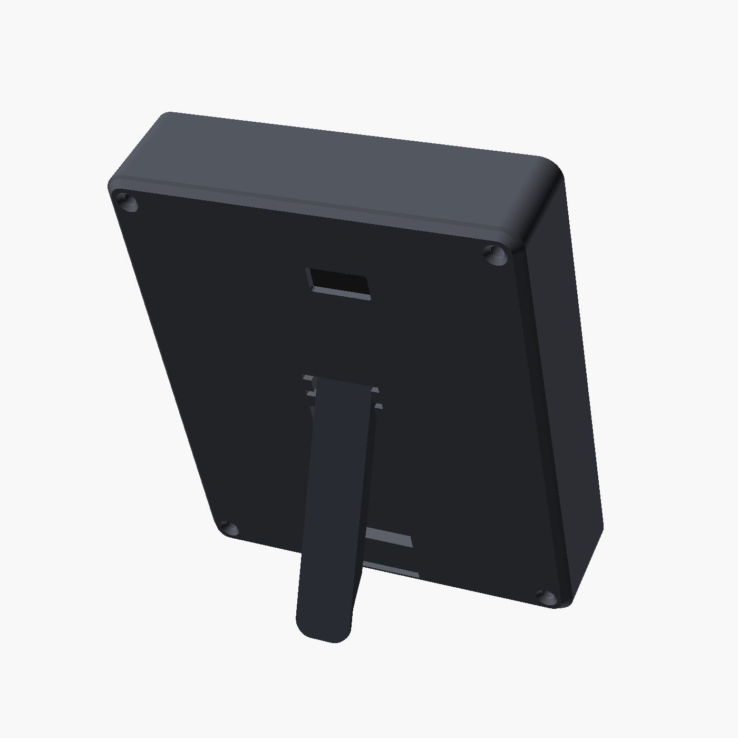
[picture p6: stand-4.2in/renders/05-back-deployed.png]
Leg deployed
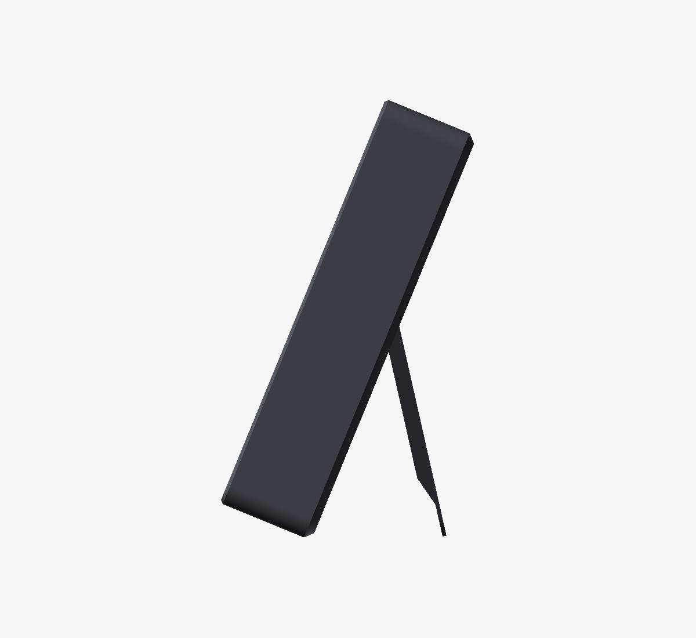
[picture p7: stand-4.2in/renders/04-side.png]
Side, leaning
  

**The leg is the only moving part.** It runs straight down the centreline, folds flush into a
recess in the back cover, and swings out 35° onto a positive stop. Portrait only.

| | |
|---|---|
| Leg | 55 mm pivot to foot tip, **13 wide** (derived), 4.0 thick at the pivot tapering to 1.0 |
| Pivot | z 58, depth 23.0 — `leg_t/2` below the back face, which is what makes the folded leg flush |
| Swing | 35°, flush to stop |
| Stance | lean **22.3°**, footprint **34.1 mm** |
| Hinge | one Ø2 × **18.0** pin, snapped into sockets on two ears **inside** the pocket |
| Fasteners | none |

### The stop is a flat, and the load is in compression

Past the pin the leg carries a **heel** reaching 4 mm beyond it. The heel is cut by the recess
floor *pulled back through the deployed angle*, so at exactly 35° a **3.07 × 14 mm flat** lands
on that floor. The load path is **leg → heel → cover, in compression**, and the display's own
weight pushes the leg *into* the stop — it is self-seating.

That is the easel hinge of [US4515338A](https://patents.google.com/patent/US4515338A/en):
*"flat stop faces … at an obtuse angle equal to the desired open angle plus 90°."*

The swept check measures the stop rather than asserting it — the leg intersected with a floor
half-space, so only the heel shows:

| Over-travel past 35° | at 35° | +0.5° | +1° | +2° | +5° |
|---|---|---|---|---|---|
| Immersed volume | **empty** | 0.56 mm³ | 1.11 | 2.22 | 5.54 |

Empty right up to the stop angle and then linear in the over-travel: that is the signature of a
face rotating into a plane. A corner grazing a plane saturates instead.

**35° is under 90° on purpose.** The heel reaches the floor only while the swing stays inside a
right angle; the same geometry also keeps every point on the leg out of the cover through the
whole stroke, which the swept `cover_legs` check confirms at every angle, not just at the ends.

### The pocket is a plain blind hollow, and the leg swings free

There is **no detent, no seat and no latch lip**. The recess is two steps in depth, two ears at
the pivot, and nothing else: no bridge across its mouth, nothing cut into its floor, and no
opening anywhere in it. The leg is a plain tapered blade with a heel on it.

The one position that is *made* is the deployed one, and it is made by a face, not by friction:
the heel's flat lands on the recess floor at 35° and the display's own weight seats it. Folded,
the leg simply lies in its pocket.

**Nothing holds the leg shut.** Tip the display far enough forward and the leg will swing out
under its own weight. That is the trade for a pocket with no features in it, and it is a
one-line reversal — `lip_h` and the bridge it drew are in git at the commit before this one.

With nothing riding the floor and nothing bridging the mouth, `cover_legs` is **empty at every
angle from 0 to 35 with nothing suppressed** — the first time in this design that has been true.

### What starts it

**Finger access comes free from the ears.** They are only 8 mm long, so away from the pivot the
leg sits in the full 18 mm pocket with **2.5 mm open either side of it, the whole length, at the
full 4.5 mm depth**. A fingernail goes straight under its side edge.

There is no separate notch band, and there should not be: the band that used to widen the pocket
for that purpose ran z 9.5 … 17.5, which is exactly where the bottom glass rib and the old port
position lived. It undercut the rib and crowded the port at once.

### The pin snaps into ears inside the pocket

The hinge is **one Ø2 × 18 mm steel rod**, and it goes in **from the back face**, through the
open mouth of the recess, under tension: two **ears** stand inside the pocket, 2.0 mm thick,
inboard of its side walls, from the pocket floor up to the back face, and each carries a Ø2.1
bore on the pivot axis whose **mouth** is only 1.51 mm across. The rod presses past that lip
and is then retained by it. Nothing else holds it — no head, clip or glue.

`pin_fit` = 0.10 mm is the running clearance, on the leg's bore and on the sockets alike.

**The ears are what keep the back face unbroken.** Bored straight outward into the pocket's side
walls instead, a socket can only be reached from *outside* the part, so its snap mouth has to
break through the back face — two more openings in a face that should have none. On an ear the
mouth opens into the pocket, and the pocket is blind, so the whole hinge is enclosed by the
cover.

**The pin length is the pocket width.** It passes through both ears and its ends finish flush
with the pocket's side walls, so the walls themselves cap it and nothing has to retain it
sideways. `leg_w` follows from the same arithmetic — `rec_w − 2 × (ear_w + rec_clr)` = 13.0 —
so the leg cannot be set inconsistently with the pocket that holds it.

**Assembly order matters here:** push the rod through the leg first (2.5 mm proud each side),
then press that subassembly into the pocket from the back so both rod ends snap into their
ears. The rod cannot be fitted afterwards — the leg's bore is a closed hole, not a slot.

### The pocket is a pocket, and that has to be built

`cover()` is a 1.4 mm skin plus a 1.0 mm register plate — 2.4 mm of material — and the pocket is
**4.5 mm deep**. Cut into that alone it does not make a pocket, it makes a hole. What used to
stop it being one was the battery platform happening to sit behind part of it, which left a
**7.75 mm band between the shallow step and the platform's start that was open straight into the
interior.**

So the pocket is bored into a boss of its own, `recess_boss()`, running its whole deep length
with its front face at depth 18.7 — the floor is 1.8 mm everywhere rather than only where
something else reaches. Below the boss's start (solid frame is behind the cover there)
`stand_register()` extends the register plate down the pocket's footprint instead, with a
matching relief in the frame, so that band keeps 1.0 mm behind it.

**The boss overruns the deep pocket at both ends, and that is not a detail.** An *end wall*
needs material behind it exactly as a floor does, and the pocket's two end walls face along the
long axis rather than through the thickness — so a check that probes "behind the floor" never
touches them. Started on the same plane, as the boss and the deep section were, the deep
section's lower end wall has **nothing** behind it: an **18 × 2.1 mm slot straight out of the
leg pocket into the electronics bay**, with every other check in the file passing. The boss now
starts `rec_floor` below the step (`boss_z0` 9.5, `shl_z0` 11.3) and runs `rec_floor` past
`rec_top` (`boss_z1` 65.3), so both end walls have 1.8 mm of boss behind them.

That slot is also the one the cover's **genus** was counting: the pocket and the interior are
both open to air, so joining them made a loop through the solid. The cover is genus 5 now —
four screw holes and the port, and nothing else goes through it.

`chk="rec_floor_gap"` is the guard: slabs immediately behind the pocket, less the cover. Anything
the cover does not fill is a hole. It tests each band at its own floor depth — the deep section
against the full `rec_floor` = **1.8 mm**, since nothing is cut into the floor, and the shallow
section against the register plate alone — **and it now tests the two end walls as well**, which
is the probe that was missing. Put the boss and the deep section back on one plane and it reports
62.7 mm³ at x ±9, z 7.75…9.45: the hole, named and located.

### The floor plate has to die in solid frame

That register extension is a **plug**: the cover carries it, the frame is relieved `reg_fit` =
0.15 mm larger to receive it, and so a 0.15 mm gap runs all the way round it. Where that gap
comes out decides whether the case is sealed, and it is the one place on the part where the
answer is not obvious.

The **rear chamfer takes `rear_chf − cover_t` = 0.6 mm off the frame's back face** at the bottom
edge — it has to, or the frame and cover would not meet flush there. A plug that reaches below
that line is no longer plugging anything: both parts have been chamfered away around it, the
0.15 mm gap surfaces in the chamfer, and it leads **straight into the hollow bottom end wall**.
A 21 × 1.3 mm slot into the inside of the frame, right where the folded leg's foot sits.

So the plate stops at `reg_ext_z0` = **z 1.9**, which leaves `reg_seal` = **1.15 mm** of solid
frame below the relief, and `rec_z0` is derived as `foot_z − rec_clr` = **2.5** rather than a
millimetre lower than it needs to be — every millimetre the pocket runs down is a millimetre
nearer that chamfer. The `POCKET FLOOR PLATE` echo states both numbers and says which way the
test came out.

**And the bottom end wall is not hollowed at all.** `lightening()` runs at the **top end only**.
The bottom end wall is the one the stand pocket lies against, and that pocket's floor is the
1.0 mm register plate — which is an *outside* surface. Hollowed out behind it, that plate was
the only thing between an open pocket on the outside of the case and the inside of the frame,
and the pocket was a 73.6 × 4.5 mm open space in the frame's back face into the bargain. Left
solid, the leg's pocket is a blind hollow in a solid block with nothing behind it to get into.

It costs **6.28 cm³** — about 7.8 g, the frame going from ~62 g to ~70 g. That is the price of
the answer to "what is behind the pocket floor?" being "frame".

### The glass ribs keep their root

Two ribs on the cover press the display forward onto the front lip. Nothing else holds it back —
the interior has to be open behind the glass or the glass could not get in — so these are
structural, and their **root** is what makes them work.

The bottom one crosses the stand pocket, so it is drawn as **two 15 mm segments outboard of it**,
at x ±10 … ±25, with 1.0 mm of boss wall between each segment and the pocket. Run straight
through, the pocket cut its root away over the pocket's full width and left the middle of a
26 mm rib cantilevered off 5.7 mm at one end — a 20 × 3.5 × 20.7 mm wall hanging off the part
that is supposed to hold the display down.

`chk="rib_recess"` is the guard: the ribs against the pocket volume, which must be empty. No
interference check could see the original fault, because nothing intersected — the material was
simply gone.

### The recess steps, and the leg tapers to match

The recess is 18 mm wide and 4.5 mm deep down to z 11.3. Below that the cover is backed by solid
frame, so it steps to 1.4 mm. The leg's taper is **one-sided** — the back face stays flush the
whole length and the front face rises — and it **finishes** at z 11.3 rather than running on to
the tip, so the thin end matches the shallow section instead of standing proud of it. That is
`shl_z0`, so the taper follows the step automatically wherever the step goes.

### The stand subassembly — parts, print, assembly

| | Qty | Notes |
|---|---|---|
| **Leg** `stl/leg.stl` | 1 | 2.59 cm³, ~3.2 g. Carries the heel and its flat, and the axle hole |
| **Pin, Ø2 × 18.0 mm** | 1 | = the pocket width, so its ends finish flush with the pocket walls. Steel rod, or a turned-down 1.75 mm filament offcut |
| Fasteners | **none** | no screws, no inserts, no clips |

**Printing.** The leg goes on the bed as exported — flat, its front face upward. Print it
**with supports**: the heel's stop flat is an overhang at 35°. That is the only part of it that
needs them, and it is the only part in the build that does.

**Assembly**, in order:

1. Push the **rod** through the leg's axle hole, 2.5 mm proud each side.
2. Press that subassembly into the recess from the back, so both rod ends snap past the ears'
   socket lips.
3. Fold the leg down into the pocket. Nothing catches it there — it simply lies flush.

**Taking it apart** is the reverse: lever the leg back out and the rod comes with it.

### Where the recess costs nothing

The recess is a 16 mm band on the centreline. The **driver carrier spans x −41.45…−11.45 and
misses it entirely**, so it datums to the cover's register face at depth 22.6 and the driver
column has **17.45 mm against a measured 16.0 mm stack — 1.45 mm spare**, once `carrier_lift`
has taken its 2.5.

The **cell does** cross the band, so it rides a platform level with the back of the recess floor
at depth 18.7 rather than straddling the step.

### The stance

The frame rests on the **rear** edge of its flat bottom — a slab leaning backwards contacts at
the back of its base. The 2 mm rear chamfer moves that contact edge forward to depth 23.0, and
the estimated centre of mass sits 9.9 mm behind it.

Folded, the leg's foot tip stops at z 3.0 against a chamfer that ends at z 2.0, so **nothing
overhangs the bottom edge**. `dep_ang` sets the lean and `leg_len` sets the footprint,
independently.

---

---

## Parts and printing

Sheet 4 — frame

Sheet 5 — back cover

Sheet 6 — leg and pivot

The STLs export ready to slice — **no rotating in Orca**. Supports are needed on the leg and
nowhere else. This is the three printed parts exactly as the exporter leaves them, which is how
they land on the bed:

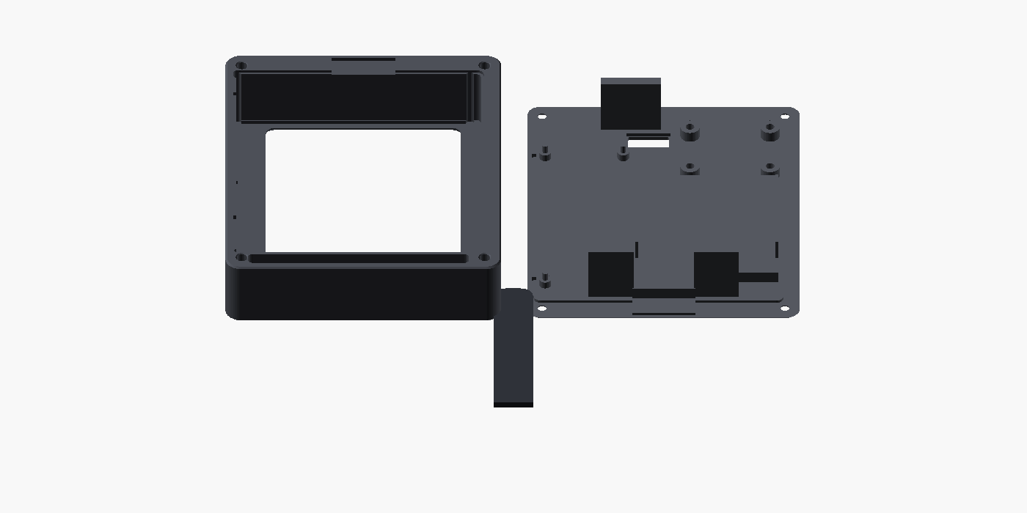
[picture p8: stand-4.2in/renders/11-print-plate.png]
The three parts as exported


| Part | STL | On the bed | Why | Filament |
|---|---|---|---|---|
| Frame | `stl/frame.stl` | front face down | big flat first layer, and the interior opens upward. The other way up, the 1.4 mm front plate has to bridge the whole interior | ~70 g |
| Back cover | `stl/cover.stl` | outer back face down | big flat first layer, standoffs and ribs build upward | ~35 g |
| Leg | `stl/leg.stl` | flat, front face up | **the one part that wants supports** — the heel's stop flat is a 35° overhang. Flat also puts the leg's bending load across the layers rather than along them | ~3.2 g |
| Bezel test tile | `stl/bezel_test.stl` | front face down — **print this first** | same as the frame | ~23 g |

PLA or PETG, 0.2 mm layers, 4 perimeters, 15–20% infill. On the frame and cover only the
0.8 mm front chamfer overhangs, at 45°, on the first layer. Put the visible face on the bed;
that surface finish is most of the look.

The **top** end wall is hollowed from the cover side (`lightening()`), leaving 2 mm of floor
behind the glass shelf, a rim, and the screw bosses. The **bottom** one is left solid: the stand
pocket lies against it — see *The floor plate has to die in solid frame*.

### Hardware

- 2 × **Ø8 × 2 mm N42 disc magnets**, glued onto the back face at x ±27.6 (optional).
  Only if the fridge door is actually magnetic: test first
- 4 × **M2.5 heat-set inserts**, 4.0 OD × 4.0 long, in the frame's end walls
- 4 × **M2.5 countersunk screws**, 8 mm, for the cover
- 1 × **Ø2 × 18.0 mm pin** for the hinge. It snaps into the two ears inside the pocket, and
  the pocket walls cap its ends; nothing else retains it
- 1 × **Waveshare FPC adapter**, 18 × 32, plus a second FPC to the driver board. It is
  **taped down, not screwed** — its four corner holes go unused
- **Double-sided 0.1″ prototype board, 30 × 70**, with four Ø2.0 mounting holes at 26 × 66
  centres (driver carrier + divider). It drops onto four printed pegs; no cutting needed
- 2 × **19-pin 2.54 female headers** for the driver to plug into
- **Panel-mount USB-C pigtail**, 14 × 4.5 snap-in body (measured)
- Adafruit **bq25185 (#6091)**; 1S LiPo **2000 mAh, 694449, 44 × 49 × 6.9 mm** (the
  salvaged cell above)
- JST-PH pigtails, and **foam** double-sided tape — for the glass, the cell, the charger
  and the FPC adapter. Foam rather than film: the adapter's tape has to absorb the ribbon's
  spring-back, and peel is its failure mode

---

## Verification

**Print `bezel_test.stl` first.** It is an `intersection()` of the actual `frame()` with a
box — the front 6.85 mm of the full 91.9 × 108.4 face — so it cannot drift from the part it
stands in for. ~40 minutes, ~20 g. It shows all four glass-pocket corners with their relief,
all four cavity corners, all four bezels, the complete window lip and chamfer, and the full
ribbon slot, and you can drop the real module into it. Its depth tracks the ribbon relief
(`rib_y1 + 1.4`) rather than being a round number, because a fixed 5.65 left a 0.2 mm
membrane across the relief floor — a slot that printed closed. `bt_h = 34` gives the old
bottom-band tile if you only want the corners.

**Geometry checks that pass now:**

| Check | State |
|---|---|
| Bodies per part | **1 each, all four** — count the bodies, do not infer it from the edge check |
| Watertight | yes, all four — 0 non-manifold edges |
| `frame_module` at `cav_rel = 0`, `cav_r = 1.5`, `pan_rel = 1.4` | clear, 0.086 mm to spare on the sharp PCB corner |
| Interference set | all empty or zero-volume, **0 real** |
| Screws | 4, one near each corner, each in 13.75 mm of end wall |

The two zero-volume results are `frame_cover` (the frame's rear face and the cover's front
face are both at `y = body_d`) and `cover_board` (the board sits exactly on its standoffs);
`intersection()` returns coincident faces as zero-thickness sheets, so measure volume, not
emptiness. The other trap: when an intersection *is* empty, OpenSCAD writes no file at all,
so a script that reuses output paths silently re-reads the previous check's result — delete
the output before every run.

Both of the interferences this model used to carry are gone, and both went for the same
reason — they were consequences of hardware this build does not have:

| Check | Was | Now |
|---|---|---|
| `conn_cell` | 154 mm³ — a mated header against the cell | empty; `mod_header = false`, nothing stands off the panel |
| `drv_module` | 1050 mm³ — a 15 mm driver stack against a module PCB | empty: no module PCB to hit |

`cover_legs` is the one that must stay clean, and it must stay clean **through the whole
stroke**, not just at the two ends. **One** thing in it is an interference by design:

It is now **empty at every angle from 0 to 35, with nothing suppressed** — no detent riding the
floor, no lip biting the tip, nothing in the pocket for the leg to touch but the pin. Any volume
at all from this check is a real clash.

`heel_floor` is the check that proves the stop, and it is read as a *transition* rather than as
a pass: empty at every angle up to and including 35°, then 0.56 mm³ at 35.5° growing linearly.

`rec_frame` is the depth guard — the volume the recess needs against `frame()`. It comes back
zero-volume, a coplanar touch where the shallow recess floor meets the frame's face, which is
the tightest it can be without interfering. `frame_cover` cannot substitute for it, because
that check is a zero-volume touch by design and would hide a real overlap.

`adapt_board` is the one genuine conflict in the build: the adapter overlaps the carrier for
31.25 mm. It is not a by-design touch and it does not have a fix yet. `adapt_cover` comes
back zero-thickness, which is the adapter's back face sitting flush on the pocket face.

Two problems caught during the rebuilds:

- the cover's −X driver rail sat 1.4 mm outside the interior wall and buried itself in the
  frame — 459 mm³ of `frame_cover`. That rail is gone now with the carrier.
- **the interior was walled shorter than the glass**, so the panel could not be installed at
  all. No interference check catches that, because nothing intersects: the glass simply has
  no path in. It is now a stated constraint (`glass_pass_h`) with its own echo line.

`mock_module()` draws the glass as a **sharp-cornered square**, matching the real part,
which is what makes `frame_module` able to catch a corner-fillet problem at all.

### Thin, but deliberate: the −X wall

Because the ribbon relief sets `W`, everything on the −X edge is tight, and the features
there are cavity-referenced:

| | Wall left |
|---|---|
| outboard of the ribbon relief | 1.00 mm |
| −X and +X walls generally | 4.92 mm |
| each long-axis end wall | 13.75 mm — this is where the screws go |

All printable at a 0.4 mm nozzle. The register slot is the one to watch if `W` ever comes
down further — it thins 1:1 with the outer face.

**The screws are in the end walls, not the side walls.** 38.03 mm from the centreline and
7 mm from each end, so each is near a corner and each sits in 13.75 mm of material — about
4 mm clear of the outer edge and 4 mm clear of the interior. The side walls are 4.92 mm and
could not have taken them, which is exactly the trap the old design was in: a single spine
of three screws down the +X side, and the whole −X edge unfastened.

### Heat-set inserts, and why the screws are countersunk

The frame takes **M2.5 heat-set inserts**: a Ø3.6 bore, 5.0 mm deep, with a lead-in chamfer
so the insert starts square. Melt them in flush with the mating face.

The screws are **countersunk, not socket cap**, because the cover is 1.4 mm thick. A 90°
head sinks `(head Ø − clearance Ø) / 2` deep, which for M2.5 is **1.05 mm** — it disappears
into a 1.4 mm plate. A socket cap head is 2.5–3 mm tall and would stand proud of the back
face, and there is nowhere to put a boss to swallow it: the cover meets solid frame there,
not open interior.

| Size | Insert OD × L | Bore | Screw head, 90° | Cone depth |
|---|---|---|---|---|
| M2 | 3.2 × 4.0 | Ø2.9 × 5.0 | 4.0 | 0.8 |
| M3 | 4.6 × 5.7 | Ø4.0 × 6.7 | 6.0 | 1.3 |
| **M2.5** | **4.0 × 4.0** | **Ø3.6 × 5.0** | **5.0** | **1.05** |

Insert dimensions vary by brand — measure yours and set `ins_d` / `ins_l`. Everything
downstream follows, including the cover's clearance hole and countersink.
`insert_fit = false` goes back to self-tapping screws into a Ø2.1 pilot.

### One known cosmetic defect

The cover exports with **10 non-manifold edges** — edges used by four facets instead of two,
where two surface patches meet along a line. They are not holes: CGAL rates the result
`Simple: yes / Volumes: 2`, the solid is closed, and slicers take it. They sit in the
`rear_chamfer()` hull region at the outer back face (a 0.04 mm sliver at y 24.96–25.00, plus
one at y 22.05–22.25), and they are **not** parameter-dependent. The frame uses the same
chamfer code and is clean, so it is the interaction with the cover's rear-face features.
Left alone deliberately — `rear_chamfer()` is delicate code, and a cosmetically nicer mesh
is not worth reopening it.

---

## Exporting and tuning

```bash
openscad -o stl/frame.stl      -D 'part="frame"'      src/epaper_stand.scad
openscad -o stl/cover.stl      -D 'part="cover"'      src/epaper_stand.scad
openscad -o stl/leg.stl        -D 'part="leg"'        src/epaper_stand.scad
openscad -o stl/bezel_test.stl -D 'part="bezel_test"' src/epaper_stand.scad
```

Regenerate the drawings from the model after any parameter change:

```bash
openscad -o /tmp/p.stl -D 'part="params"' src/epaper_stand.scad 2>&1 \
  | sed -n 's/^ECHO: "P|\(.*\)"$/\1/p' | tr '|' '=' > /tmp/params.txt
python3 tools/mkdrawings.py     # drawings/sheet*.svg + _sheets.json
python3 tools/mkpage.py         # drawings/index.html
```

And the renders, which import the STLs rather than the model — re-export the STLs first,
or the pictures will show the previous revision:

```bash
sh tools/mkrenders.sh           # renders/*.png, all of it from stl/
```

### The Fusion hand-off

[`fusion/`](fusion/) carries the same model as an Autodesk Fusion starting
point: the measured inputs as user parameters, the eight component envelopes as
named keep-out bodies, eight DXF section profiles, reference meshes in model
orientation, and the vendor solid models that exist. All of it is generated, in
the model's own coordinate system rather than print orientation, so everything
lands on one origin — and all of it works on the **Personal** licence, which is
why the meshes are written as STL as well as 3MF.

```bash
sh tools/mkfusion.sh            # fusion/*, all of it from src/epaper_stand.scad
```

[`fusion/README.md`](fusion/README.md) is the way in, and
[`fusion/vendor/SOURCES.md`](fusion/vendor/SOURCES.md) lists every drawing,
datasheet and CAD model published for each part in the build.

| Want | Change |
|---|---|
| A panel with a PCB behind it is used after all | `bare_panel = false` — the interior goes back to being sized by `pcb_w` / `pcb_h` |
| A module with a mated header is used after all | `mod_header = true`, then `conn_h` / `conn_dx` / `conn_dz` |
| Screws further from / closer to the corners | `scr_cx` / `scr_cz` |
| A different insert size | `insert_size` = `"M2"` / `"M2.5"` / `"M3"`, or `ins_d` / `ins_l` directly |
| Self-tapping screws instead of inserts | `insert_fit = false` |
| A different perfboard | `perf_w` / `perf_h`, or `perf_fit = false` |
| The electronics box needs to grow | `elec_clr`, `col_gap`; the interior follows, and so does the frame if it has to |
| The driver stack measures deeper than 16 mm | `drv_stack` — and then the depth has to grow or the board has to come off the pocket |
| Bigger cell | `bat_w` / `bat_h` / `bat_t` — the band is 79.5 wide × ~51 tall |
| Three side buttons | `btn_n = 3`, then `btn_d` / `btn_sp` |
| More/less white line | `white_show_short` / `white_show_long` |
| Different lean | `dep_ang` — it sets the lean and nothing else; `leg_len` sets the footprint |
| Rear port position | `ucb_x` / `ucb_z`; `port_w` / `port_h` for the opening. Watch `PORT CLEARANCES` — it must not end up in a band with another opening |
| Deeper/shallower back bevel | `rear_chf` — 2.0 is the ceiling before it eats the 2.2 mm walls |
| Different fridge magnets | `mag_d` / `mag_t` — they set `mag_x`, so both glue positions move and the echo re-reports them. `mag_fit = true` sinks them into pockets instead, with `mag_clr` for the bore and `mag_sink` for how far below the face they sit |
| More/less air under the carrier for its solder joints | `carrier_lift` (2.5) — it comes straight out of the driver column's 1.45 mm of spare |
| A different charger's hole spacing | `chg_hx` / `chg_hz` (26.67 × 20.32 for the 6091, off its STEP); `chg_ins_d` / `chg_ins_l` for a different insert, `chg_skin` for the material left behind the bore |
| Looser/tighter leg in its recess | `rec_clr` (0.35 a side) |
| Open the flash port again | `flash_port = true` |

Preview modes: `standing`, `folded`, `guts` (cover populated with mock electronics),
`assembly`, `exploded`, `plate`.

Interference checks are built in — `chk` = `frame_cover`, `frame_module`, `cover_module`,
`cover_board`, `frame_board`, `drv_module`, `conn_cell`, `conn_board`, `conn_cover`,
`adapt_board`, `adapt_cover`, `rec_frame` (the recess must not reach into the frame — the
depth guard), and the two swept ones, which take `chk_th`: `cover_legs` walks the leg's whole
travel against the cover, and `heel_floor` asks whether the heel has reached the recess floor
at a given angle, which is what proves the stop.

**An empty intersection writes no file at all**, so `rm -f` the output before every run or a
stale result gets read back as a clash. Two of the checks are *meant* to report volume:
`frame_cover` is a zero-volume touch (both faces at `y = body_d`), and `cover_board` is
16.70 mm³ — the four carrier pegs through holes `mock_board` does not model. Everything else,
`cover_legs` included, must be empty:

```bash
openscad -o /tmp/chk.stl -D 'part="none"' -D 'chk="cover_board"' src/epaper_stand.scad

# the leg's whole stroke against the cover -- every angle must write NO FILE
for t in 0 5 10 17.5 25 30 35; do
  rm -f /tmp/chk.stl
  openscad -o /tmp/chk.stl -D 'part="none"' -D 'chk="cover_legs"' -D "chk_th=$t" \
    src/epaper_stand.scad 2>/dev/null
  [ -f /tmp/chk.stl ] && echo "theta $t CLASHES"
done

# and the stop: empty at every angle up to dep_ang, growing past it
for t in 30 34 35 35.5 36 38; do
  rm -f /tmp/chk.stl
  openscad -o /tmp/chk.stl -D 'part="none"' -D 'chk="heel_floor"' -D "chk_th=$t" \
    -D 'det_tot=0' src/epaper_stand.scad 2>/dev/null
  [ -f /tmp/chk.stl ] && echo "theta $t -- heel is on the floor"
done
```

## Sources

- [4.2inch e-Paper Module (B) manual — 91 × 77 × 1.05 mm panel, 84.8 × 63.6 active](https://www.waveshare.com/wiki/4.2inch_e-Paper_Module_(B)_Manual)
- [e-Paper ESP32 Driver Board pinout and "5V pin supports 3.6V to 5.5V… can be powered by a lithium battery"](https://spotpear.com/index/study/detail/id/375.html)
- [e-Paper ESP32 Driver Board product page — `<2mA` low-power current with the CP2102 unpowered](https://www.waveshare.com/e-paper-esp32-driver-board.htm)
- [Fasani — measured 10–13 mA "deep sleep" on this board](https://fasani.de/2020/04/19/waveshare-eink-esp32-driver-board/)
- [e-Paper ESP32 Driver Board V3 schematic](https://files.waveshare.com/wiki/E-Paper-ESP32-Driver-Board/E-Paper_ESP32_Driver_Board_V3.pdf) — 24-pin FPC panel interface with the panel DC-DC on board, CH343 USB-UART behind SW1, GPIO 4 gating the panel rail
- [Adafruit bq25185 charger, #6091](https://www.adafruit.com/product/6091) · [pinouts](https://learn.adafruit.com/adafruit-bq25185-usb-dc-solar-lithium-ion-polymer-charger/pinouts) · [TI BQ25185](https://www.ti.com/product/BQ25185)
- [Perma-Proto quarter-size — 1.7″ × 2.0″, holes 1.4″ apart](https://www.pololu.com/product/2765)
</content>

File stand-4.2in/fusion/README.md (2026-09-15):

# Fusion hand-off

Everything needed to rebuild this frame in Autodesk Fusion: the measured
numbers, the component envelopes, sketch profiles of every feature, and the
vendor solid models that exist.

Regenerate the whole folder from the OpenSCAD model with

```bash
sh tools/mkfusion.sh
```

Only [`README.md`](README.md) and [`vendor/`](vendor/) are written by hand.
Everything else comes out of `src/epaper_stand.scad`, so it cannot drift from
the model or from the drawings.

The CSVs and the DXF sketches come out byte-identical run to run. The meshes do
not: OpenSCAD writes the same triangles in a different order each time, so
`git diff` will report `mesh/*.stl` and `mesh/*.3mf` as changed after any
regeneration even when the model has not moved. The geometry is the same — it
was checked triangle-for-triangle — so that diff is noise, not a change.

---

## The origin, first

One coordinate system runs through all of it — the OpenSCAD model's, in
millimetres:

| | |
|---|---|
| **X** | short axis. 0 is the centre, so the frame runs −45.95 … +45.95 |
| **Y** | depth. **0 is the outer front face**, and +Y goes back into the part |
| **Z** | long axis. 0 is the bottom edge, so the frame runs 0 … 110.5 |

Portrait. Say *short axis* and *long axis*, never width and height, for
anything belonging to the display — the model's own header explains why, and it
is the mistake that has cost this build the most time.

Nothing in this folder is in print orientation. The meshes, the DXF sketches
and the keep-out bodies all land on that one origin, so anything imported sits
where it belongs without being moved.

## On the Personal licence

This hand-off is built for Fusion **Personal**, and everything in it works
there. Worth knowing before you start:

- **Scripts and the API are available.** The setup script below is the main
  route in, and Personal does not restrict it.
- **STEP imports and exports.** The vendor charger model opens directly.
- **DXF (2D) imports.** All eight sketch profiles open.
- **3MF is not on Personal's format list**, so every mesh here is written as
  **STL as well** — reach for the `.stl` first and treat the `.3mf` as a bonus
  where Insert Mesh accepts it.
- **Ten active documents.** Each vendor model you upload takes one of them, and
  so does each part you model. PDFs and images do not count. When the count gets
  tight, deactivate what you are not editing — read-only documents are
  unlimited and nothing is lost.

Nothing here needs DWG, sheet metal, simulation, generative design or CAM, all
of which Personal restricts.

## Start here: run the script

[`scripts/EinkStandSetup/`](scripts/EinkStandSetup/) is the fastest way in. In
Fusion: **Utilities → ADD-INS → Scripts and Add-Ins → Scripts → the green + →
pick the `EinkStandSetup` folder → Run.** The folder holds the script and its
manifest, which is the layout Fusion's script picker expects.

It creates 105 user parameters, each carrying its comment from the OpenSCAD
source, and builds the eight component envelopes as bodies named
`KEEPOUT_PANEL_GLASS`, `KEEPOUT_DRIVER_BOARD` and so on, in the root component.
Run it again after re-generating and it updates the parameters in place and
rebuilds the keep-outs.

They go in the root component rather than one of their own because a **Part
Design** document may hold only one component, and this has to work in a part as
much as in an assembly. The `KEEPOUT_` prefix is what groups them: it sorts them
together in the Browser, so you can click the first, shift-click the last and
press **V** to hide all eight at once.

If it stops on something, it names the stage it stopped on. Neither half of it
is load-bearing: [`parameters.csv`](parameters.csv) and
[`keepouts.csv`](keepouts.csv) hold exactly the same numbers, and eight boxes
placed by hand from the CSV take about five minutes.

## The keep-outs

Eight bodies, one per thing that occupies space inside the case. They are
reference geometry: model the frame and cover around them, and if plastic and a
keep-out ever share space, the plastic is wrong. Full extents are in
[`keepouts.csv`](keepouts.csv).

| Body | Size, X × Y × Z | What it is |
|---|---|---|
| `PANEL_GLASS` | 76 × 1.05 × 90 | the bare glass, sharp corners, offset −3.2 in X to centre the ink |
| `FPC_HOLLOW` | 3 × 4.05 × 49 | where the panel's tail folds back through 180° |
| `DRIVER_BOARD` | 29.46 × 6 × 48.25 | Waveshare ESP32 driver board, whole component envelope |
| `DRIVER_CARRIER` | 30 × 1.6 × 70 | the perfboard the driver plugs into |
| `FPC_ADAPTER` | 18 × 5 × 32 | the service loop, taped to the back of the glass |
| `CHARGER` | 32 × 7.2 × 26.3 | Adafruit bq25185, board and USB-C jack |
| `CELL` | 44 × 6.9 × 49 | 2000 mAh LiPo pouch |
| `USB_C_PIGTAIL` | 14 × 10 × 4.5 | the snap-in rear port |

Three of them are deliberately larger than the part:

- `DRIVER_BOARD` is the full 6.0 envelope over the tallest component, not the
  1.6 bare board. The cover's rails overlap the board's edge by 1.0 to grip it,
  so an envelope at board thickness would read those rails as a clash.
- `FPC_HOLLOW` is sized for the fold, not the ribbon. It spans 14.5 below the
  tail's exit and 34.5 above it, which covers the tail at anything from 18 to
  24 long.
- `CELL` is squared off at 44 × 49; the real pouch has roughly R2 corners.

The whole stack has one tight dimension and it is the depth budget: the driver
board, its female sockets and the carrier measure **16.0** back-face to tallest
point, against **17.45** available — the register face gives 19.95 and
`carrier_lift` takes 2.5 of it to clear the solder joints under the carrier.
Everything else has room.

## Parameters

The two CSVs are split on purpose.

**[`parameters.csv`](parameters.csv)** — 114 rows, and every one of them is a
number that was measured or chosen. Nothing in the file is computed from
anything else in it, so each row is a value to type in once and then own. Rows
beginning `#` are group headings; drop them if an importer objects.

**[`reference-dimensions.csv`](reference-dimensions.csv)** — 268 rows, every
value the OpenSCAD model carries or works out: the outer 91.9 × 110.5, the
cavity, the board positions, the 22.3° lean, the derived clearances. These are
answers, not inputs. A Fusion rebuild should reach them from its own sketches
and constraints — the file is here to check against, which is why it is named
for reference and has no import format.

The Fusion script carries the same 105 parameters inline, so running it needs
no CSV at all — `parameters.csv` is there for reading, and for importing without
running a script. To go through the CSV instead, the **Parameter I/O** add-in reads
`"name","unit","expression","comment"` with every field quoted, which is the
format the file is written in — the quoting matters, because unquoted fields
make the add-in drop the first parameter.

Parameters the OpenSCAD source carries but that drive no geometry in it — the
FPC socket's own width, the adapter's PCB thickness and screw holes, the
carrier's pads, the flash-port opening — are collected in the last
group, marked as such. They are real measurements of real parts and may well
drive geometry in a Fusion rebuild even though they no longer do here.

## Sketch profiles

Eight DXF files, all in millimetres. **One sketch each, on its own plane** —
they are section cuts through the finished solid, not stages that combine into
it. See [Building the frame, step by step](#building-the-frame-step-by-step) for what each one is the
reference for. Check the extents against the table before building on anything:
a DXF that lands on the wrong plane or the wrong scale looks plausible until it
does not.

| File | Plane and cut | Sketch X | Sketch Y | Expected extents |
|---|---|---|---|---|
| [`dxf/front.dxf`](dxf/front.dxf) | frame silhouette from the front | model X | model Z | 91.90 × 110.50 |
| [`dxf/pocket.dxf`](dxf/pocket.dxf) | section at Y 1.925, through the glass pocket | model X | model Z | 91.90 × 110.50 |
| [`dxf/cavity.dxf`](dxf/cavity.dxf) | section at Y 6.65, inside the PCB cavity | model X | model Z | 91.90 × 110.50 |
| [`dxf/cover_in.dxf`](dxf/cover_in.dxf) | section at Y 23.1, just inside the cover | model X | model Z | 83.30 × 101.85 |
| [`dxf/cover_back.dxf`](dxf/cover_back.dxf) | cover silhouette from the back | model X | model Z | 90.72 × 109.41 |
| [`dxf/side.dxf`](dxf/side.dxf) | centreline section at X 0, frame and cover together | model Z | model Y | 110.50 × 25.00 |
| [`dxf/leg_side.dxf`](dxf/leg_side.dxf) | the leg's side profile, folded | model Z | model Y | 59.00 × 4.85 |
| [`dxf/layout.dxf`](dxf/layout.dxf) | the eight keep-out footprints in plan | model X | model Z | 83.10 × 90.00 |

Two of those extents are worth reading rather than skimming:

`cover_back.dxf` is 90.72 × 109.41, not 91.90 × 110.50. The cover's skin lives
entirely inside the 2.0 rear chamfer, so the chamfer trims its whole outline by
0.59 a side. The frame is the part that is 91.9 wide; the cover never is.

`layout.dxf` draws each footprint as a 0.1 mm outline rather than a filled
rectangle. The boxes overlap in plan — the cell sits behind the charger's
column — and a projection would union them into one silhouette, losing the
thing the sketch is for. It is a visual aid: two edges land within 0.02 mm of
each other (the driver board's −X edge against the glass's, at −41.18 and
−41.2) and merge into one line at that outline thickness, so take exact extents
from [`keepouts.csv`](keepouts.csv), not by measuring the imported sketch.

## Building the frame, step by step

**The DXFs do not combine into the part.** They are horizontal slices through a
solid that already exists, taken at four different depths, plus two vertical
sections and a layout. Lofting or joining them would produce nothing meaningful:
the features they show are pockets at different depths, not one cross-section
evolving through the part.

Build it from the numbers instead. **Every cut in this frame is a rounded
rectangle or a circle**, at a known centre, size and depth — so the whole part
is one extrude followed by twelve pocket cuts, each drawn from four numbers. The
DXFs are how you *check* a cut once it is made, not how you make it.

The numbers below are the model's own, from
[`reference-dimensions.csv`](reference-dimensions.csv). Parameter names are given
in brackets: type `65` now, and swap in `win_w` later when you want the sketch
to follow the parameter.

### Does this reproduce the STLs?

Yes, for all three printed parts. Every cut the OpenSCAD model makes is listed
here — the frame below, then [the cover](#building-the-cover) and
[the leg](#building-the-leg) — with the two features the model carries but
disables in this build called out so you do not model something that is not
there.

What you will not get is a byte-match, and you would not want one. The STLs are
faceted: a Ø2.1 bore in `frame.stl` is a 48-sided polygon. Fusion gives you a
true cylinder. Your solid will be **dimensionally identical and geometrically
better**, and re-exporting it will not produce the same triangles.

One honest caveat:

- **The cover is roughly three times the frame's work.** Twenty-odd features,
  and the pivot ears and their C-sockets are the hardest geometry in the build.
  Do the frame first.

### Before you start

1. **File → New Design.**
2. In the Browser (left panel), expand **Document Settings**, hover over the
   units, click the button that appears, and set **Millimeter**.
3. Run [`scripts/EinkStandSetup/`](scripts/EinkStandSetup/) — see
   [Start here](#start-here-run-the-script). You now have the parameters under
   **MODIFY → Change Parameters**, and eight translucent bodies named
   `KEEPOUT_*` sitting exactly where the electronics go.

Leave the keep-outs visible the whole way through. They are the check on every
cut you make: **plastic and a keep-out must never share space.**

### Make the offset planes first

Every cut starts at a known depth, so build all the planes up front and you will
not have to break out of sketching later. For each one:

**CONSTRUCT → Offset Plane** → click the **XZ plane** in the Browser (under
Origin) → type the distance → **OK**.

Make six: **1.4**, **2.65**, **4.65**, **21.1**, **22.45**, **22.6**.

Watch the preview. Y runs *back into the part*, away from the front face, and the
planes have to march back toward the keep-outs. If a plane jumps the wrong way,
put a minus sign in front of the number. Rename each one in the Browser to its
distance (double-click it) — you will be picking them by name.

### The repeating recipe

Steps 2 to 12 are all the same five moves. Once through it and the rest are
mechanical:

1. **CREATE → Create Sketch**, then click the plane the step names.
2. **CREATE → Rectangle → Center Rectangle.** Click anywhere near the right
   spot, then click again to make a rectangle. Do not try to be accurate — the
   dimensions come next.
3. Press **D** (Sketch Dimension) and add four dimensions: the rectangle's
   **width**, its **height**, and its centre point's **horizontal** and
   **vertical** distance from the origin point. Type the step's numbers in.
   Where a step gives **centre X of 0**, do not dimension it — select the
   rectangle's centre point and the origin point and apply a **Vertical
   constraint** instead. It is cleaner than a zero dimension and it cannot drift.
   The sketch turns black when it is fully constrained; that is the signal every
   dimension has landed.
4. If the step gives a corner radius: **CREATE → Sketch Fillet**, click the four
   corners, type the radius, Enter.
5. **FINISH SKETCH**, then **CREATE → Extrude** (shortcut **E**). Click inside
   the rectangle to select the profile, set **Distance**, and set **Operation**
   to **Cut**. If the preview cuts forward out of the part instead of back into
   it, put a minus in front of the distance.

The one thing to watch on every extrude is the **direction**. Y increases going
back into the part, so every cut but none of the chamfers travels that way.

### Step 1 — the outer body

Sketch on the **XZ plane** itself, not an offset plane.

| Centre X | Centre Z | Width | Height | Corner R |
|---|---|---|---|---|
| 0 | 55.25 | 91.9 (`W`) | 110.5 (`H`) | 5 (`corner_r`) |

Extrude **23.6** (`body_d`), Operation **New Body**. The result must sit with its
front face on Y 0 and its back face at Y 23.6, with the keep-outs inside it. If
it went the other way, flip the distance.

Check: the body should be 91.9 wide and 110.5 tall, with its bottom edge on Z 0
and the origin at the middle of that bottom edge.

### Steps 2 to 12 — the cuts, in order

Order matters: several of these rely on material a previous step left behind.

| # | Cut | Sketch on | Centre X | Centre Z | Width | Height | R | Distance |
|---|---|---|---|---|---|---|---|---|
| 2 | Window | XZ plane | 0 | 55.25 | 65.0 (`win_w`) | 87.4 (`win_h`) | 3 | 1.4 (`front_t`) |
| 3 | Glass pocket | Y 1.4 | −3.2 (`pan_px`) | 55.25 | 77.5 | 91.5 | 0.5 (`pan_r`) | 1.26 |
| 4 | Ribbon relief | Y 1.4 | −43.45 | 65.25 (`rib_cz`) | 3.0 (`rib_clr`) | 49.0 (`rib_w`) | — | 4.05 |
| 5 | PCB cavity | Y 2.65 | −1.65 (`cav_cx`) | 55.25 | 81.6 (`cav_w`) | 92.5 (`cav_h`) | 1.5 (`cav_r`) | 20.95 |
| 6 | Lightening, top | Y 4.65 | −1.65 | 105.75 | 73.6 (`lgt_w`) | 4.5 | 1.5 | 18.95 |
| 8 | −X wall slot, lower | Y 21.1 | −43.15 | 23.25 | 1.6 | 10.0 | — | 2.1 |
| 9 | −X wall slot, upper | Y 21.1 | −43.15 | 87.25 | 1.6 | 10.0 | — | 2.1 |

**There is no lightening pocket at the BOTTOM end, and that is deliberate.** That
end wall is the one the stand pocket lies against, and the pocket's floor there is
nothing but the cover's 1.0 mm register extension — an outside surface. Hollow the
frame out behind it and that plate is the only thing between an open pocket on the
outside of the case and the inside of the frame. Left solid it costs 6.28 cm³ and
the pocket becomes a blind hollow in a solid block. Do not add a matching pocket
at the bottom "for symmetry".

**C17 needs a boss under each pocket (C7c), and the pair is mirrored in x.** The
back face has only 2.4 behind it at both spots, so each Ø8.2 × 2.2 pocket is
bored into its own Ø11.2 pad standing 1.8 off the register face — 2.0 is left in
front of each disc.

Mirrored x is the point: the pair's centroid has to sit under the case's centre
of mass, which is on the centreline, or the display hangs crooked. The two z are
**not** equal and cannot be — the −X half is carrier board from z 14.5 to 84.5
held only 2.5 off the face, and that gap belongs to the header solder joints, so
the −X pocket goes above the carrier while the +X one sits under the charger
between its two post rows. Do not "tidy" them onto one line.

A magnet is safe against everything in the case except an inductor, whose ferrite
core it can bias toward saturation. Both pockets sit clear of the driver board,
which carries the only inductors here.

**Step 10 must not reach the bottom edge.** It is the relief the cover's register
extension plugs, and it is `reg_fit` 0.15 larger than the plug all round, so a
0.15 gap runs round the plate. The rear chamfer has already taken 0.6
(`rear_chf − cover_t`) off this face at the bottom edge — so a relief that
reaches below z 0.6 puts that gap out in the chamfer, where it becomes a 21 mm
slot straight into the hollow end wall. It starts at z 1.75 and leaves 1.15 of
solid frame below it. Do not extend it "to be safe".

Steps 8 and 9 are what the **cover's two tongues hook into** — the cover carries
a 1.4 × 1.6 × 9 tongue at each of those positions, so the slot is 0.1 wider a
side and 0.5 longer at each end. Cut them undersize and the cover will not
close.
| 10 | Stand register relief | Y 22.45 | 0 | 5.73 | 21.3 | 7.95 | — | 1.15 |
| 11 | Cover register relief | Y 22.6 | −1.65 | 55.25 | 83.6 | 94.5 | 2.5 | 1.0 |
| 12 | Insert bores, ×4 | back face | ±40.45 (`scr_cx`) | 5.5 and 105.0 | Ø3.6 (`ins_d`) | — | — | 5.0 |

Steps 5, 6 and 7 all run to the back face, so instead of typing their distance
you can set the extrude's **Extent Type** to **All** and let it cut through
whatever is behind. It is the more robust choice — an exact-to-the-face distance
can leave a sliver if anything shifts later.

Four steps need something beyond the recipe:

**Step 3, the glass pocket, needs corner reliefs.** The glass has sharp corners
and a printed pocket cannot, so four circles of **R1.4** (`pan_rel`) sit centred
*on* the rectangle's corners — at X −41.95 and 35.55, Z 9.5 and 101.0. Draw them
in the same sketch with **CREATE → Circle → Center Diameter Circle**, then select
the rectangle *and* all four circles as the extrude profile. They cannot be moved
inboard; being centred on the corner is the whole function.

**Step 5, the cavity, carries the same four circles up.** Draw the same four
R1.4 circles at the same X and Z in the cavity's sketch too, or the interior wall
overhangs the pocket's reliefs by 0.9 mm.

**Step 12 uses the Hole tool, not an extrude.** **CREATE → Hole**, click the
**back face**, set **Simple**, diameter **3.6**, depth **5.0**
(`ins_l + ins_relief`), and place four of them at X ±40.45, Z 5.5 and 105.0. Then
put a **0.4** chamfer on each bore's mouth so the insert starts square.

**Steps 10 and 11 are shallow reliefs at the back**, not through-cuts. They make
room for the cover's register plate, which stands 1.0 (`reg_step`) proud of the
cover's skin.

### Step 13 — the three edge breaks, last

Chamfers go last, the way Fusion prefers. **MODIFY → Chamfer**, click the edge,
type the distance.

| Edge | Size |
|---|---|
| Outer edge of the **front** face | 0.8 (`front_chf`) |
| **Window** edge on the front face | 0.9 (`win_chf`) |
| Outer edge of the **back** face | **0.6** — see below |

**The rear chamfer is 0.6 on the frame, not `rear_chf` 2.0.** The 2.0 chamfer
belongs to the assembled device, and the frame only carries the first slice of
it: the cover sits behind the frame and finishes the rest. Measured off the
exported frame, the outer profile is full width at Y 23.0 and inset 0.59 at the
back face — a 0.6 chamfer. Put 2.0 in and you will eat 1.4 mm into walls that
are 2.2 mm thick.

### Three things the model documents but does not cut

Do not model these — they are described in the sources but disabled in this
build: the **tape pads** (`tape_r` works out to 0, so the ledge is too narrow for
them), the **USB pocket** (the driver's jack lands in the middle of the interior,
with no wall to cut), and the **side buttons** (`btn_n` is 0).

### The trap: the window and the pocket are not concentric

Step 2 centres the window at **X 0**. Step 3 centres the glass pocket at
**X −3.2**. That is deliberate and it is the single easiest thing to get wrong
here: the ink is off-centre on the glass by 3.2 (`act_off_x`), and it is the
*ink* that has to look centred in the window. Build them off the same centreline
and the white border comes out lopsided — 0.7 mm one side and 1.3 the other is
the target, and it is asymmetric on purpose.

### Checking the result

Three checks, cheapest first:

1. **The keep-outs.** Nothing you cut should ever leave plastic inside one. Hide
   your frame body and confirm all eight `KEEPOUT_*` bodies are still whole.
2. **A DXF overlay.** **INSERT → Insert DXF**, pick the plane, choose the file,
   set units to **millimeter**, and leave *Combine to a single sketch* checked.
   Put [`pocket.dxf`](dxf/pocket.dxf) on the Y 1.4 plane and
   [`cavity.dxf`](dxf/cavity.dxf) on the Y 2.65 plane; the imported outlines
   should land on your cut edges. Remember a section shows **material**, so your
   pockets appear as voids inside the outline.
3. **The mesh.** Insert [`mesh/frame.stl`](mesh/frame.stl) and look for
   daylight between it and your solid.

## Building the cover

Three times the frame's work, and the last three steps are the hardest geometry
in the build. Same origin, same recipe — sketch on an offset plane from XZ, then
extrude. The difference is that the cover **adds** as much as it cuts, so watch
the **Operation** field: it is **Join** for the first group and **Cut** for the
second.

Its outline is 90.7 × 109.3, not the frame's 91.9 × 110.5. The whole cover lives
inside the assembled device's 2.0 rear chamfer, so unlike the frame — which only
catches the first 0.6 of it — the chamfer trims the cover through its entire
1.4 thickness.

### What it adds — Operation: Join

Start with C1, then Join the rest onto it.

| # | Feature | Centre X | Centre Z | Width | Height | R | Y from | Y to |
|---|---|---|---|---|---|---|---|---|
| C1 | Register plate | −1.65 | 55.25 | 83.3 | 94.2 | 2.5 | 22.6 | 25.0 |
| C2 | Outer skin | 0 | 55.25 | 91.9 | 110.5 | 5 | 23.6 | 25.0 |
| C3 | Recess boss | 0 | 37.4 | 21.0 | 55.8 | — | 18.7 | 25.0 |
| C4 | Stand register extension | 0 | 5.73 | 21.0 | 7.65 | — | 22.6 | 23.6 |
| C5 | Glass rib, bottom, ×2 | ±17.5 | 11.75 | 15.0 | 3.5 | — | 2.90 | 23.6 |
| C6 | Glass rib, top | −11.0 | 98.75 | 20.0 | 3.5 | — | 2.90 | 23.6 |
| C7a | Carrier pads, ×4 | −39.45 and −13.45 | 16.5 and 82.5 | Ø4.0 | — | — | 20.1 | 22.6 |
| C7b | Carrier pegs, ×4 | −39.45 and −13.45 | 16.5 and 82.5 | Ø1.85 | — | — | 17.3 | 22.6 |
| C7c | Magnet bosses, ×2 | ±27.6 | 83.0 (+X) and 92.1 (−X) | Ø11.2 | — | — | 20.8 | 25.0 |
| C8 | Charger posts, ×4 | 9.65 and 34.65 | 73.35 and 92.65 | Ø6.5 | — | — | 18.8 | 23.6 |
| C9 | Battery platform | 14.35 | 42.55 | 47.6 | 50.6 | — | 18.7 | 23.6 |
| C10 | Battery fences, ×2 | −8.95 and 37.65 | 42.55 | 1.0 | 35.0 | — | 11.8 | 18.7 |
| C11 | Tongues, ×2 | −43.15 | 23.25 and 87.25 | 1.4 | 9.0 | — | 21.2 | 22.8 |

**C7 is a pad carrying a peg, and both matter.** The pad holds the carrier 2.5
(`carrier_lift`) off the register face, which is the air the header solder joints
on the board's underside need; the peg rises from the top of that pad, through
the board's hole, and locates it. The first header pin is only 2.0 from each
hole, so neither may exceed Ø4.0 across.

**C8 takes an M2 heat-set insert**, which is what makes it a post and not a pad:
bore each one **Ø2.9 × 5.0 deep** from its top face (Y 18.8) toward the back
face, so it stops at Y 23.8 and leaves 1.2 (`chg_skin`) of skin. It is a blind
bore — the back face carries no opening for the charger. The centres are
**assumed**: measure the breakout before you commit to them.

**C3 is the reason the stand pocket is a pocket.** The cover's own skin is only
1.4 thick and the pocket is 4.5 deep, so without this boss behind it the cut goes
straight through the back face. Build it before you cut the pocket.

**C3 is LONGER than C12 at both ends, by 1.8 (`rec_floor`) each, and that is the
whole point.** The pocket's two end walls need material behind them exactly as its
floor does, and they face along the long axis, so nothing that probes "behind the
floor" ever touches them. Give C3 and C12 the same ends and the lower end wall has
nothing behind it at all: an 18 × 2.1 slot out of the leg pocket into the
electronics bay. C3 runs z 9.5…65.3; C12 runs 11.3…63.5.

**C5 splits into two segments and C6 does not.** The bottom glass rib crosses the
stand pocket. Run straight through, the pocket takes its root out and leaves the
middle cantilevered off one end — and it is the rib that holds the glass down.
So the bottom one is two 15 mm segments outboard of the pocket, and the top one,
clear of the pocket, is a single 20 mm pad.

**C11 are the tongues** that hook into the frame's steps 8 and 9.

### What it cuts — Operation: Cut

| # | Cut | Centre X | Centre Z | Width | Height | Y from | Y to |
|---|---|---|---|---|---|---|---|
| C12 | Stand pocket, deep | 0 | 37.4 | 18.0 | 52.2 | 20.5 | 25.0 |
| C13 | Stand pocket, shallow | 0 | 6.9 | 18.0 | 8.8 | 23.6 | 25.0 |
| C14 | Pigtail clearance | −5.0 | 92.0 | 15.5 | 6.0 | 13.6 | 23.8 |
| C15 | Port opening | −5.0 | 92.0 | 14.3 | 5.0, R0.6 | 23.5 | 25.0 |
| C16 | Screw holes, ×4 | ±40.45 | 5.5 and 105.0 | Ø2.9 | — | 23.5 | 25.0 |
| C17 | Magnet pockets, ×2 | ±27.6 | 83.0 (+X) and 92.1 (−X) | Ø8.2 | — | 22.8 | 25.0 |

**Nothing goes back in afterwards, and nothing is cut into the floor.** The pocket
is a plain blind hollow: no detent seat, no arc track, and no lip bridging its
mouth. The floor is a flat face 1.8 (`rec_floor`) thick the whole deep length. The
only things standing in the pocket are the two pivot ears, below.

Then two things that are not rectangles.

**The countersinks.** Each screw hole needs a 90° countersink opening at the
**back** face: Ø2.9 widening to Ø5.0 (`scr_head`) over 1.05 (`scr_csk`), so from
Y 23.95 to 25.0. The Hole tool will do the bore and the countersink in one go —
pick **Countersink**, and set the countersink diameter to 5.0.

**The rear chamfer** is **1.4** here, at 45° on the outer edge, running the
cover's full thickness. Not 0.6 like the frame, and not 2.0.

### The pivot ears and their sockets — last, and in this order

The ears stand **inside** the pocket, so they have to go back on **after** the
pocket is cut, and the sockets have to be bored **after** the ears exist. Get the
order wrong and the pocket erases the ears, or the socket bores fresh air.

1. **Join two ear blocks.** Each is 2.0 (`ear_w`) wide, from the pocket floor to
   the back face — Y 20.5 to 25.0 — and 8.0 (`ear_len`) long centred on the pin:
   Z 54 to 62. One at X 7 to 9, one at X −9 to −7.
2. **Cut a Ø2.1 bore** through each ear, along X, centred at Y 23, Z 58. That is
   `pin_d` 2.0 plus `pin_fit` 0.1.
3. **Cut the C-mouth.** A slot 1.51 wide (`ear_mouth` 0.72 of the bore) running
   from the bore straight out to the back face: through each ear in X, Y 22.24 to
   25.0, Z 57.24 to 58.76.

The mouth is narrower than the bore, so the pin presses past the lip and is then
retained. It opens **into the pocket**, not through the back face — which is what
keeps the back face unbroken. Bored outward through the pocket walls instead, each
socket could only be reached from outside, and that is two more openings in a face
that should have none.
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

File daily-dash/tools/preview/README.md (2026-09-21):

# Dash preview

Draws the agenda layout to a PNG instead of to the glass, so a change can be
judged before it costs a flash and a 17-second refresh.

```sh
./render.py --sheets               # the three review sheets -- start here
./render.py -l b -s busy -t 14:30  # one frame
./render.py -l b --day             # one layout at six times across the day
```

`--sheets` empties `out/` first and writes exactly three files, numbered in the
order they are worth opening:

| File | Shows |
|---|---|
| `1-three-options.png` | The three layout directions, same busy afternoon |
| `2-hour-ruler-across-the-day.png` | The chosen layout at six times, so the scroll is visible |
| `3-hour-ruler-edge-cases.png` | A quiet day, long titles, and nothing left |
| `4-wednesday-strewn.png` | Events from 6am to 9:30pm: carried-over events, a collapsed run, an overnight tail |
| `5-overloaded-day.png` | 17 events, more than the hour view can hold, so the list takes over |

Single frames land in `out/frames/`, so the top of `out/` stays reviewable.
`-s` picks a sample agenda: `busy`, `light`, `wordy`, `empty`.

## Why it is faithful

| | Panel | Preview |
|---|---|---|
| Canvas | 300 x 400 portrait | same |
| Inks | white, black, red | same three, no others |
| Type | ESPHome 1-bit glyphs | `fontmode = "1"`, antialiasing off |
| Faces | Roboto via gfonts | the same TTFs, from `.esphome/font/` |

A layout that fits here fits on the panel, and text that is legible here is
legible there. What the preview does not show is the e-ink contrast itself --
black is a dark grey on light grey paper, so the real panel reads softer than
the PNG.
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

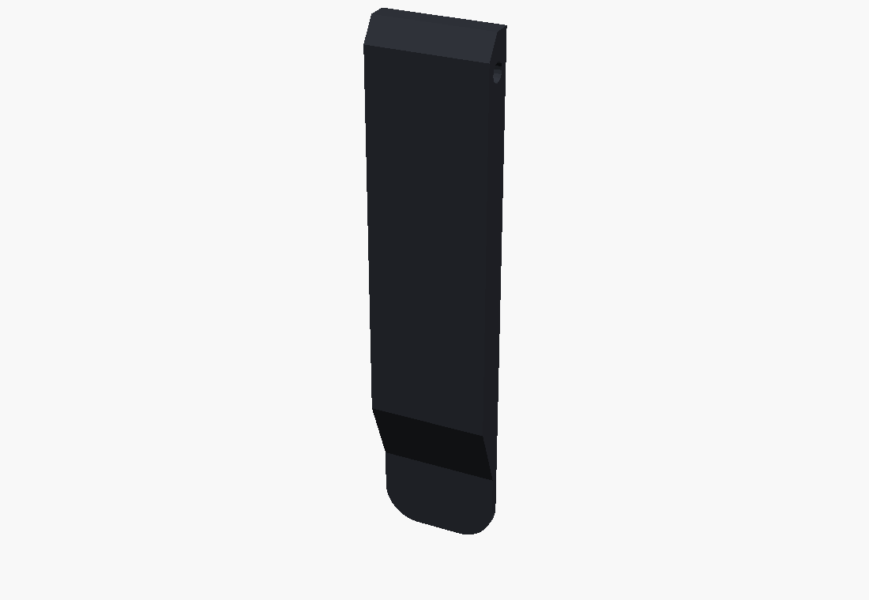
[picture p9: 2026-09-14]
stand-4.2in/renders/10-leg.png

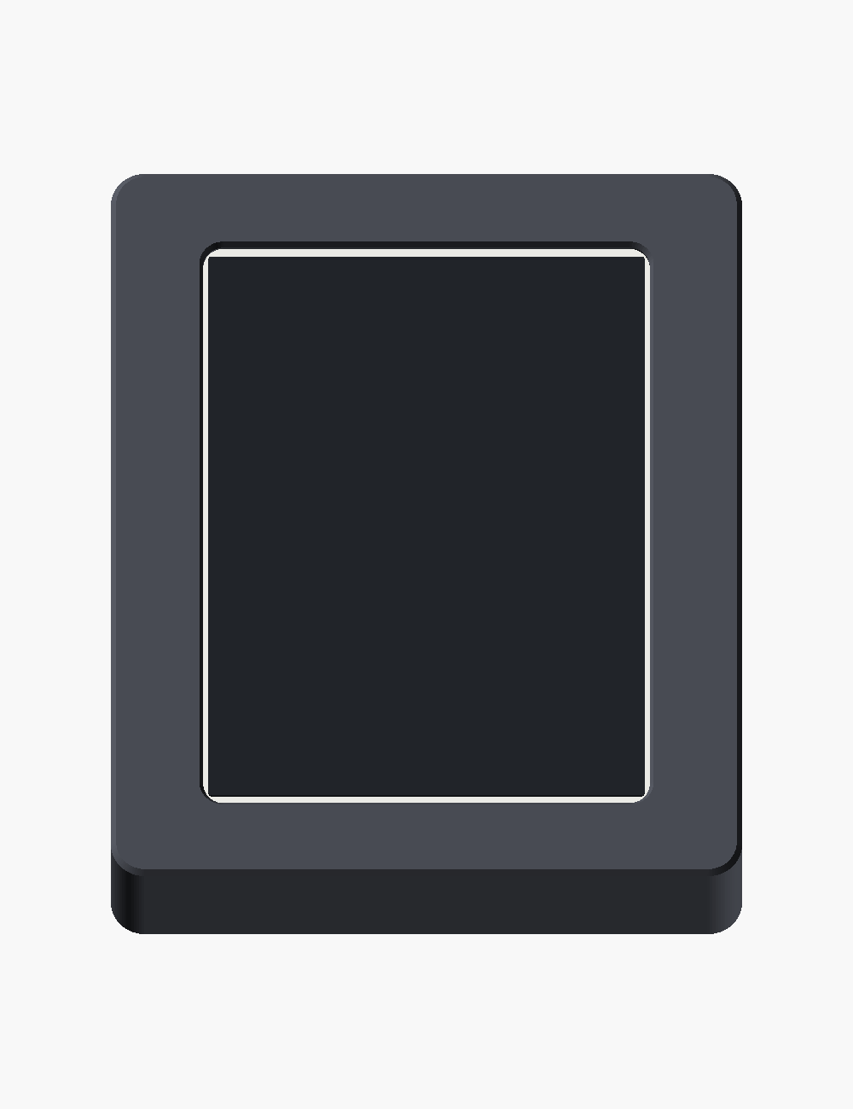
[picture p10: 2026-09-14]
stand-4.2in/renders/03-front.png

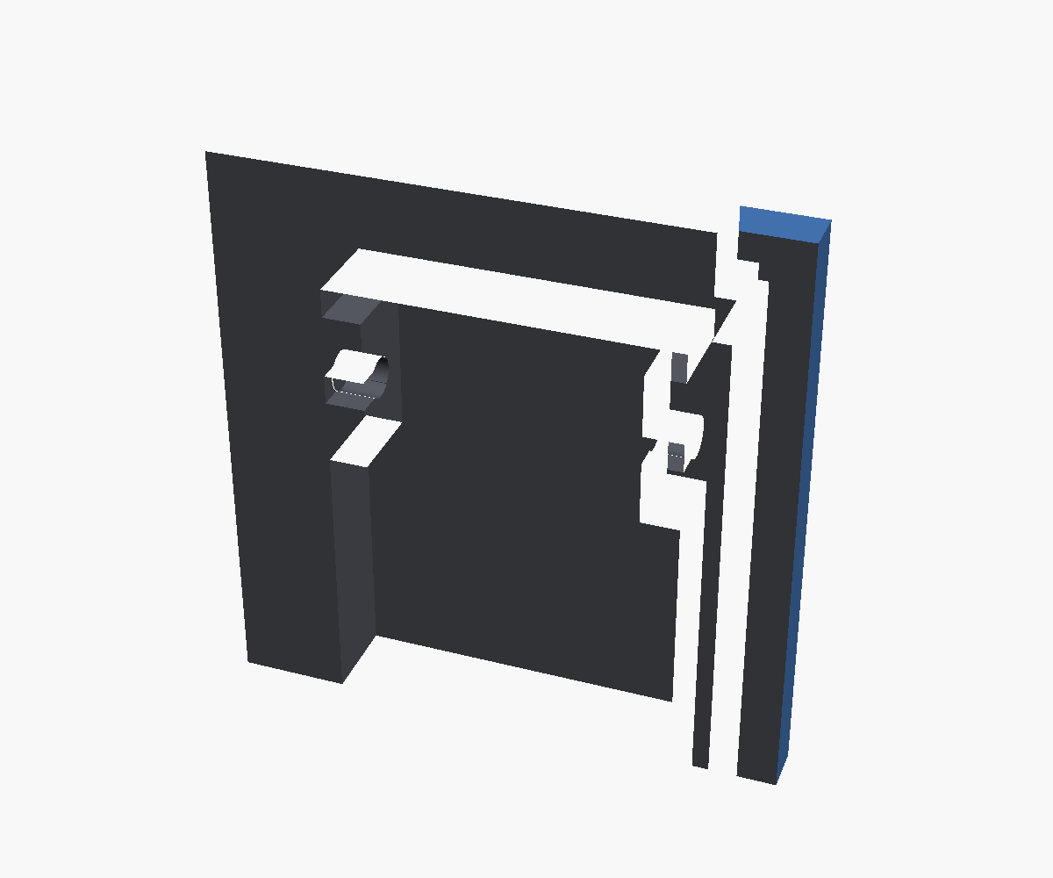
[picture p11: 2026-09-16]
stand-4.2in/renders/09-cover-recess.png

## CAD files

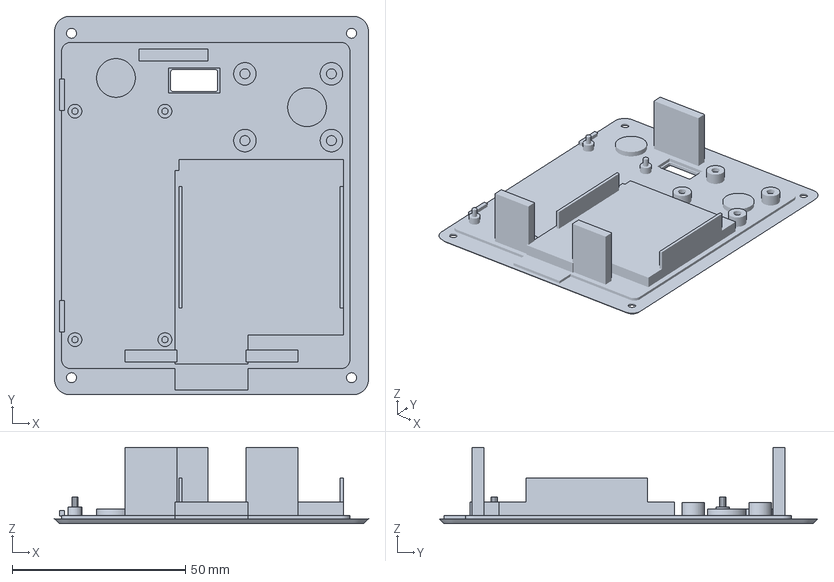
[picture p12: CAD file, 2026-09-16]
stand-4.2in/slicer/assembly-test.3mf
90.7 x 109.3 x 22.1 mm

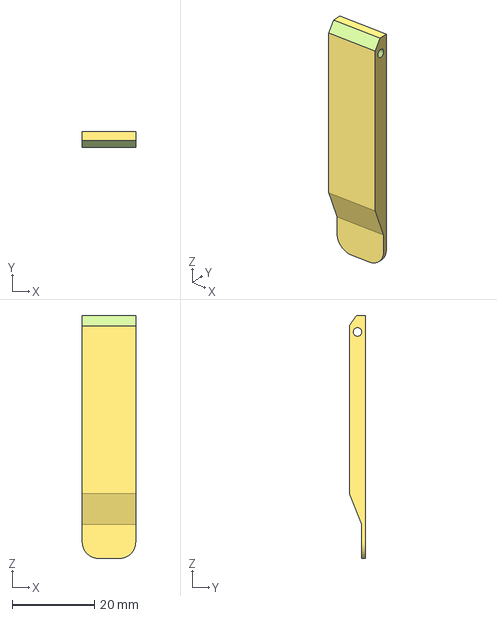
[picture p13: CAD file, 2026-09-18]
stand-4.2in/fusion/mesh/leg.3mf
13.0 x 4.00 x 59.0 mm

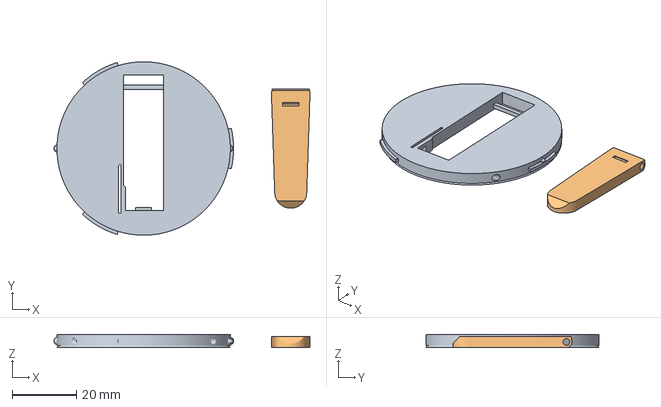
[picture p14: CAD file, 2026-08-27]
stand-4.2in/slicer/leg-test.3mf
79.7 x 54.0 x 4.00 mm
disc.stl
leg.stl

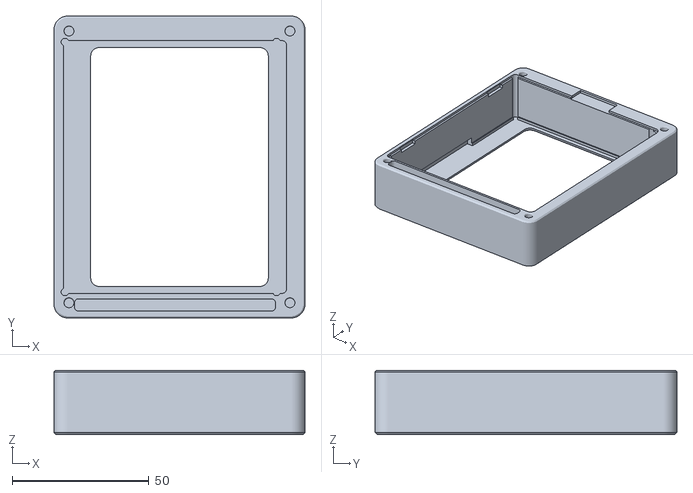
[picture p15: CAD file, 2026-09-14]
stand-4.2in/stl/frame.stl
91.9 x 110.5 x 23.6

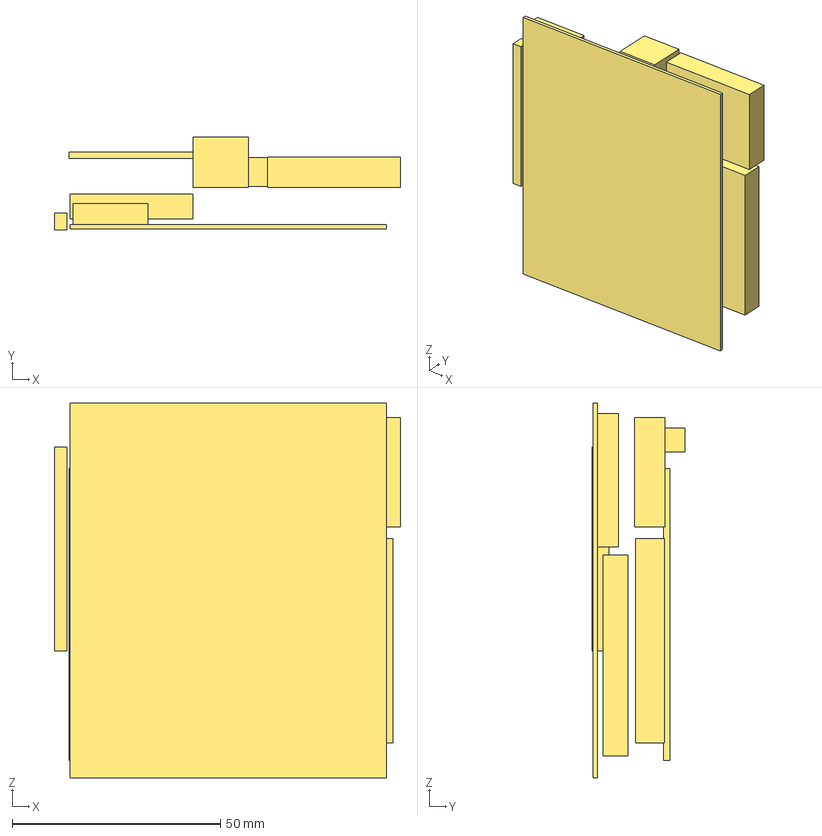
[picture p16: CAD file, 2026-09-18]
stand-4.2in/fusion/mesh/keepouts.3mf
83.1 x 22.2 x 90.0 mm

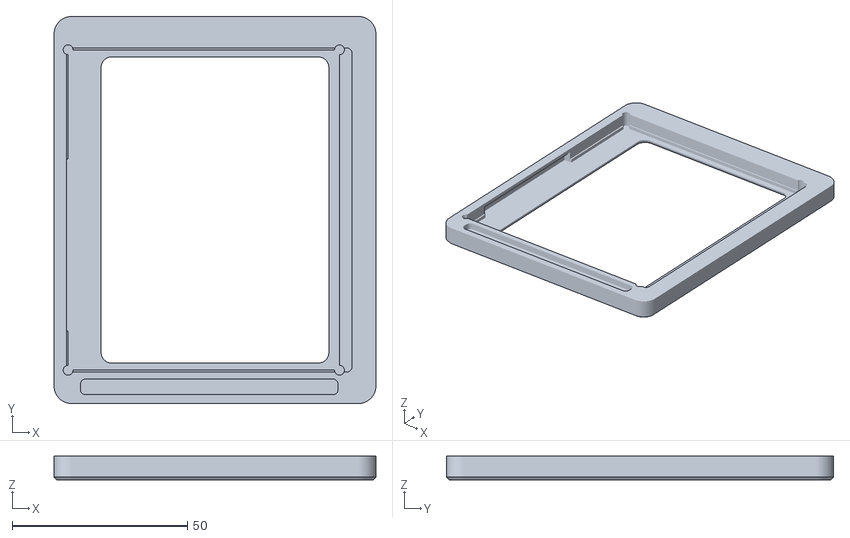
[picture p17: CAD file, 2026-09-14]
stand-4.2in/stl/bezel_test.stl
91.9 x 110.5 x 6.85

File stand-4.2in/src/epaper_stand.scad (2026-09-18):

// =====================================================================
//  4.2" e-Paper desk frame  -  "minimal bezel + snap-out kickstand"
//  Waveshare 4.2inch e-Paper Module (B) + e-Paper ESP32 Driver Board
//
//  Frame  : bezel = the panel's own dead border + ~2 mm plastic
//  Cover  : full back, carries the driver board + the stand recess
//  Leg    : the ONLY moving part.  Folds flush into the recess, swings out
//           dep_ang onto a flat on its heel.  Portrait only.
//
//  ----------------------------------------------------------------- axes
//  X = short axis, Y = depth (0 = front face), Z = long axis (0 = bottom edge)
//
//  Say SHORT AXIS and LONG AXIS, never width/height, for anything belonging to
//  the display.  Width and height swap over when the frame is turned, so a
//  measurement called "width" is ambiguous unless the orientation is also
//  stated - which is how 91 and 77.5 both got read as the wrong dimension once.
//    short axis  glass 76, PCB 78.5.  Model X.  Horizontal in portrait (the
//                default).
//    long  axis  glass 90, PCB 103.  Model Z.  Vertical in portrait.  THE RIBBON
//                LEAVES THE GLASS ON A LONG-AXIS EDGE and runs ALONG the long
//                axis before it turns back out - see RIBBON RELIEF below.
//    depth       normal to the glass, 0 at the outer front face.  Model Y.
//                This is the axis that points UP off the print bed, so "taller"
//                or "more room on top" in slicer terms means DEEPER here.
//
//  ------------------------------------------------- the three nested recesses
//  Front to back, each with its own name.  They are not interchangeable:
//    WINDOW       the through-opening the ink is seen through.  win_w x win_h.
//    GLASS POCKET the shallow step the glass sits in.  pan_* parameters.
//    PCB CAVITY   the deep recess behind it, for the module PCB.  cav_* .
//
//  ---------------------------------------------------------------- vocabulary
//  BEZEL      the visible plastic between the window edge and the outer edge.
//             Never the pocket, and not a "bevel" - a bevel is an angled edge.
//  CHAMFER    a 45 deg edge break: front_chf, win_chf, rear_chf.
//  CLEARANCE  the gap between a part and the recess holding it.  Quoted as the
//  (= MARGIN)  TOTAL across an axis, not per side: "margin 1.5 on the short
//             axis" means 0.75 a side.
//  RELIEF     material taken away at a CORNER so a sharp-cornered part can seat
//             in a printed corner.  Always centred on the corner - that is the
//             whole function, so it cannot be "moved inboard".  Two of them,
//             and they are different things:
//               pocket relief  pan_rel, at the glass pocket corners
//               cavity relief  cav_rel, at the PCB cavity corners
//  RIBBON RELIEF  the notch outboard of the glass pocket's thick-bezel edge -
//             a LONG-AXIS edge - that carries the ribbon.  Seen from the rear,
//             the ribbon leaves that edge, turns 90 deg to run ALONG the long
//             axis, then turns 90 deg back out to the header, which is why the
//             notch is a 40 mm slot along the edge and not a local pocket.
//             Three independent sizes, deliberately not called w/h/d:
//               OUT   rib_clr, outboard from the pocket edge (short axis)
//               DEEP  rib_dep, past the glass back face (depth)
//               LONG  rib_w,  along the pocket edge (long axis)
//  WHITE SHOW white_show_short / white_show_long, the panel's own white border left
//             visible inside the window on purpose.  One per axis.
//
//  ------------------------------------------------------------------- parts
//  FRAME front shell | COVER back | LEG kickstand |
//  BEZEL TEST TILE  the front-face-only print for checking fit before the frame
// =====================================================================

/* [What to build] */
// frame | cover | leg | bezel_test | plate | standing | folded | assembly | exploded | guts
part = "standing";

/* [Display module] */
// BARE PANEL: glass plus its FPC tail, and nothing else.  The tail plugs
// straight into the 24-pin socket on the driver board, which carries the
// panel's own DC-DC (VCOM / VSH / VSL / PREVGH / PREVGL) - that socket is the
// bare-panel interface, which is why there is no PCB behind the glass and no
// 8-pin header anywhere in the build.
//
// The 78.5 x 103 PCB below belongs to the *module* version of this panel.  It
// is not fitted here.  It used to set the cavity, and through it the frame's
// long axis and its 2.2 mm end walls - which is why there was nowhere to put a
// corner screw.  With bare_panel the interior is sized by the electronics
// instead, and the walls come back.
bare_panel = true;
pcb_w = 78.5; pcb_h = 103.0; pcb_t = 1.6;
// glass and ink, MEASURED on the actual module (Andy, rev E):
//   glass 76 x 90, sharp corners.  Dead border 3.0 on three sides,
//   9.4 on the ribbon side (that is the "10 mm" one, on the 76 axis).
pan_w = 76.0; pan_h = 90.0;  pan_t = 1.05;
act_w = 63.6; act_h = 84.8;
bez_thin = 3.0;                     // dead border, three sides
bez_thick = pan_w - act_w - bez_thin;   // ribbon side  -> 9.4
pan_off_x = 0.0; pan_off_z = 0.0;   // glass centre vs PCB centre  <- STILL TO MEASURE
act_off_x = (bez_thick - bez_thin)/2;   // ink centre vs glass centre -> 3.2
act_off_z = 0.0;
mod_clr = 0.5;
cav_rel = 0;                        // cavity corner relief: NOT NEEDED any more.  It only
                                    // ever existed because cav_r was 2.0, which is larger
                                    // than a sharp PCB corner can sit in - the corner poked
                                    // 0.121 mm past the arc, so a relief circle was added
                                    // to cut it away.  Shrinking cav_r below 1.707 fixes
                                    // the cause instead; frame_module is clear at cav_rel=0
                                    // with cav_r=1.5, with 0.086 mm to spare.
pan_clr_w = 0.75;                   // pocket clearance per side across the WIDTH (76 axis)
pan_clr_h = 0.75;                   //   ... and across the LONG axis.  Deliberately loose
                                    //   (1.5 mm total): a printed 91.0 measured short, so
                                    //   this is sized for print variance and the glass is
                                    //   taped rather than press-fitted.
pan_r   = 0.5;                      // pocket corner radius (relief handles sharp corners)
pan_rel = 1.4;                      // pocket corner relief, so sharp glass corners seat
// ---- THE RIBBON ROUTE, measured looking at the REAR FACE, panel in portrait.
// Sides are TOP / RIGHT / BOTTOM / LEFT (see the README): TOP and BOTTOM are the
// short-axis edges, LEFT and RIGHT the long-axis ones, and the tail leaves the
// RIGHT side.  In model terms RIGHT is -X and TOP is +Z.
//
// The tail leaves the CENTRE of the RIGHT side and makes an S:
//   leg 1  out rib_out from the glass edge
//   leg 2  90 deg turn toward the TOP, rib_band wide, rib_run long
//   leg 3  90 deg turn away from the RIGHT side, i.e. inboard across the rear
//
// It used to be an input pair, rib_off + rib_w, set from "the ribbon is towards
// the top".  It is not towards the top - it EXITS at the centre and TRAVELS
// toward the top - so both are derived from the route now and cannot drift.
rib_exit = 0.0;                     // exit centre, along the long axis, from the
                                    //   glass centre.  0 = dead centre.
rib_out  = 4.0;                     // leg 1, out from the glass edge
rib_band = 9.0;                     // ribbon width through the turn
rib_run  = 20.0;                    // leg 2, toward the TOP
rib_leg3 = 10.0;                    // leg 3, inboard across the rear face.  It
                                    //   only has to LAND on the adapter, not hit
                                    //   a socket - the tail folds over onto it,
                                    //   and the cable on from the adapter to the
                                    //   driver is routed by hand, so nothing
                                    //   downstream of the adapter is constrained.
rib_clr_out = rib_out;              // leg 1's reach, named for the echo
rib_marg = 10.0;                    // relief margin around the route, along the
                                    //   long axis.  OVERSIZE IS FREE HERE - the hollow
                                    //   is only ever a problem when it is too SMALL -
                                    //   so this is set generously rather than to the
                                    //   route.  At 10 the hollow spans 14.5 below the
                                    //   exit and 34.5 above, which covers leg 2 running
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

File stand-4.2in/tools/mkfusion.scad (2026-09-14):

// =====================================================================
//  Fusion hand-off exports.
//
//  Everything here is produced from src/epaper_stand.scad itself, in the
//  MODEL's own coordinate system - X short axis, Y depth (0 = outer front
//  face), Z long axis (0 = bottom edge) - not in print orientation.  That is
//  the whole point: the meshes, the DXF sketches, the keep-out bodies and
//  fusion/parameters.csv all land on the same origin, so anything imported
//  into Fusion lines up with everything else without being moved.
//
//  part="none" is passed on the command line so the model's own output
//  dispatch renders nothing and only the target below is emitted.
//
//  Driven by tools/mkfusion.sh - see that file for the full export list.
// =====================================================================
include <../src/epaper_stand.scad>

// mesh: frame | cover | leg | keepouts
// dxf : front | pocket | cavity | cover_in | cover_back | side | leg_side | layout
target = "frame";

// ---------------------------------------------------------- section planes
// A section normal to Y (a front view at depth y0) lands the model's XZ plane
// on the sketch plane: sketch X = model X, sketch Y = model Z.
module sec_y(y0) projection(cut=true) translate([0,0,y0]) rotate([-90,0,0]) children();
// A section normal to X (a side view at x0): sketch X = model Z, sketch Y = model Y.
module sec_x(x0) projection(cut=true) translate([0,0,x0]) rotate([0,90,0]) children();
// The silhouette seen from the front, no cut.
module plan()   projection(cut=false) rotate([-90,0,0]) children();

// ------------------------------------------------------------- keep-outs
// Every envelope the electronics claim: name, X centre, X size, Y start, Y
// depth, Z centre, Z size.  ALL BOXES, including the cell - the real pouch has
// R2 corners, and a keep-out that ignores them is the conservative way round.
//
// tools/mkfusion.py builds the same list from the same parameter dump for
// fusion/keepouts.csv and for the Fusion script, so the two cannot disagree
// unless one of them is edited by hand.  Don't.
ko = [
  ["PANEL_GLASS",    pan_px, pan_w, front_t+0.15, pan_t, Zc+pan_off_z, pan_h],
  ["FPC_HOLLOW",     pan_px - (pan_w + 2*pan_clr_w)/2 - rib_clr/2, rib_clr,
                     front_t, pan_t + rib_dep, rib_cz, rib_w],
  ["DRIVER_BOARD",   drv_cx, drv_w, drv_back - drv_env, drv_env, drv_cz, drv_h],
  ["DRIVER_CARRIER", carrier_cx, carrier_w, carrier_face, carrier_t, carrier_cz, carrier_h],
  ["FPC_ADAPTER",    adapt_cx, adapt_w, mod_back, adapt_env, adapt_cz, adapt_h],
  ["CHARGER",        chg_x_c, chg_w, chg_back - chg_t, chg_t, chg_z, chg_h],
  ["CELL",           bat_cx, bat_w, rec_back - bat_t, bat_t, bat_cz, bat_h],
  ["USB_C_PIGTAIL",  ucb_x, snap_w, cov_in - snap_d, snap_d, ucb_z, snap_h],
];
fitted = [ for (b = ko)
             if (!(b[0]=="DRIVER_CARRIER" && !carrier_fit) &&
                 !(b[0]=="FPC_ADAPTER"    && !adapt_fit)   &&
                 !(b[0]=="USB_C_PIGTAIL"  && !port_snap)) b ];

module keepouts(){
    for (b = fitted)
        translate([b[1], b[3], b[5]]) xzext(b[4]) square([b[2], b[6]], center=true);
}
// The same footprints in plan, as OUTLINES.  Drawn in 2D rather than projected:
// the boxes overlap in plan (the cell sits behind the charger's column), and a
// projection unions them into one silhouette, which loses the very thing the
// sketch is for.
lay_t = 0.1;                        // outline thickness
module keepouts_plan(){
    for (b = fitted)
        translate([b[1], b[5]]) difference(){
            square([b[2], b[6]], center=true);
            square([b[2] - 2*lay_t, b[6] - 2*lay_t], center=true);
        }
}

// ------------------------------------------------------------------ mesh
if      (target=="frame")      frame();
else if (target=="cover")      cover();
else if (target=="leg")        leg_placed(0);      // as fitted, folded
else if (target=="keepouts")   keepouts();
// ------------------------------------------------------------------- dxf
else if (target=="front")      plan() frame();
else if (target=="pocket")     sec_y(front_t + pan_t/2) frame();
else if (target=="cavity")     sec_y(mod_back + 4) frame();
else if (target=="cover_in")   sec_y(cov_in - 0.5) cover();
else if (target=="cover_back") plan() cover();
else if (target=="side")       sec_x(0) union(){ frame(); cover(); }
else if (target=="leg_side")   sec_x(0) leg_placed(0);
else if (target=="layout")     keepouts_plan();

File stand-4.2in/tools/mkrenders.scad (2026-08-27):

// =====================================================================
//  Renders built from the EXPORTED STLs, not from the model's geometry.
//
//  Every solid in these pictures is imported from stl/*.stl, so what you see
//  is what the slicer gets.  The model is included only for its numbers - the
//  placement maths and the mock electronics, which have no STL because they
//  are not printed.
//
//  Each STL is exported print-ready: rotated flat-face-down, in the hand it is
//  designed in - there is no mirroring.  The stl_* modules below undo exactly
//  that rotation, so the parts come back into model space and assemble.  If a
//  part's export orientation changes in the model, change it here too.
//
//  PORTRAIT ONLY: the leg runs down the centreline and the stand has one
//  orientation, so there is one standing view.
//
//  Usage (see tools/mkrenders.sh):
//    openscad -o out.png -D 'part="none"' -D 'view="iso_p"' \
//             --imgsize=1400,1400 --camera=... tools/mkrenders.scad
// =====================================================================
include <../src/epaper_stand.scad>

view = "iso_p";

// ---------------------------------------------------------------- parts
// inverse of:  translate([0,H,0]) rotate([90,0,0]) frame()
module stl_frame(){
    rotate([-90,0,0]) translate([0,-H,0]) import("../stl/frame.stl"); }

// inverse of:  translate([0,0,depth]) rotate([-90,0,0]) cover()
module stl_cover(){
    rotate([90,0,0]) translate([0,0,-depth]) import("../stl/cover.stl"); }

// inverse of:  leg()  ->  leg_shape() in its own frame
module stl_leg_shape(){
    rotate([-90,0,0]) import("../stl/leg.stl"); }

// the model's leg_placed(), on the STL.  Same +theta sign - the foot swings OUT.
module stl_leg_placed(theta){
    translate([0, piv_y, piv_z]) rotate([theta,0,0]) stl_leg_shape(); }

module stl_bezel_test(){
    rotate([-90,0,0]) translate([0,-H,0]) import("../stl/bezel_test.stl"); }

// ------------------------------------------------------------ assemblies
module stl_device(theta=0, guts=true){
    color("#4c4f57") stl_frame();
    color("#54575f") stl_cover();
    if (guts) { mock_module(); mock_board(); }
    color("#2e3138") stl_leg_placed(theta); }

// The lean is DERIVED at the top level of the model, so this consumes it rather
// than re-deriving it.  This file used to carry its own copy of that arithmetic
// and the two could drift.
module stl_standing(theta=dep_ang){
    a = (theta == 0) ? 0 : lean;
    translate([0,0,py_edge*sin(a)]) rotate([-a,0,0]) stl_device(theta);
}

// ----------------------------------------------------------------- views
if      (view=="iso_p")      stl_standing();
else if (view=="iso_fold")   stl_standing(0);
else if (view=="front")      stl_standing();
else if (view=="side")       stl_standing();
else if (view=="back_dep")   stl_standing();
else if (view=="back_fold")  stl_device(0, guts=false);
else if (view=="cover_in")   color("#54575f") stl_cover();
// the recess, the arc detent track and the pin sockets, from behind and close in
else if (view=="cover_rec")  intersection(){
                                 color("#54575f") stl_cover();
                                 translate([-(rec_w/2+rec_wall+4), rec_back-1,
                                            piv_z-18])
                                     cube([rec_w+2*rec_wall+8,
                                           depth-rec_back+2, 30]); }
else if (view=="leg")        color("#2e3138") stl_leg_shape();
else if (view=="bezel_test") color("#4c4f57") stl_bezel_test();
// internal layout: the printed cover as exported, with the electronics that
// are NOT printed drawn from the model
else if (view=="guts")       { color("#54575f") stl_cover(); mock_board(); mock_adapter(); }
// the three printed parts exactly as the exporter leaves them - already
// flat-face-down, so nothing here rotates them.  This is the orientation that
// lands on the bed when you open the STL in the slicer.
else if (view=="plate")      {
    color("#4c4f57") translate([-50, 0, 0]) import("../stl/frame.stl");
    color("#54575f") translate([ 50, 0, 0]) import("../stl/cover.stl");
    color("#2e3138") translate([  0,-40, 0]) import("../stl/leg.stl"); }

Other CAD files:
stand-4.2in/fusion/dxf/cover_in.dxf
stand-4.2in/stl/cover.stl
stand-4.2in/fusion/dxf/side.dxf
stand-4.2in/fusion/mesh/cover.3mf
stand-4.2in/fusion/dxf/cover_back.dxf
stand-4.2in/fusion/dxf/layout.dxf
stand-4.2in/fusion/mesh/frame.3mf
stand-4.2in/stl/leg.stl
stand-4.2in/fusion/dxf/front.dxf
stand-4.2in/fusion/dxf/cavity.dxf
stand-4.2in/fusion/dxf/leg_side.dxf
stand-4.2in/fusion/dxf/pocket.dxf
stand-4.2in/archive-v1-wedge/epaper_stand.scad
stand-4.2in/archive-v1-wedge/bezel_test.stl
stand-4.2in/archive-v1-wedge/cover.stl
stand-4.2in/archive-v1-wedge/frame.stl
stand-4.2in/archive-v1-wedge/kickstand.stl
stand-4.2in/fusion/mesh/cover.stl
stand-4.2in/fusion/mesh/frame.stl
stand-4.2in/fusion/mesh/keepouts.stl
stand-4.2in/fusion/mesh/leg.stl
stand-4.2in/src/epaper_stand_v2.scad
stand-4.2in/src/epaper_stand_v3.scad
stand-4.2in/src/epaper_stand_v4.scad

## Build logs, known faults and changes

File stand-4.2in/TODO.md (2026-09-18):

# TODO — 4.2" e-Paper desk frame

Open action items, in the order they block each other. Everything here was pulled out of
the [README](README.md), which now describes only what the build *is*.

Re-export and re-draw after any parameter change:

```bash
openscad -o /tmp/p.stl -D 'part="params"' src/epaper_stand.scad 2>&1 \
  | sed -n 's/^ECHO: "P|\(.*\)"$/\1/p' | tr '|' '=' > /tmp/params.txt
python3 tools/mkdrawings.py && python3 tools/mkpage.py

for p in frame cover leg bezel_test; do
  openscad -o stl/$p.stl -D "part=\"$p\"" src/epaper_stand.scad
done
sh tools/mkrenders.sh
sh tools/mkfusion.sh
```

The renders import `stl/*.stl`, so re-export the STLs before re-rendering or the pictures
will show the previous revision. `tools/mkfusion.sh` reads the model directly and rebuilds
everything in [`fusion/`](fusion/) — parameters, keep-outs, DXF sections and meshes.

---

## 1. Still to measure — blocks the print

Answered and now in the model: the driver stack (16.0), the USB-C body (14 × 4.5), the
adapter's depth (`adapt_env` 5.0), the carrier's mounting holes (Ø2.0 at 26 × 66 centres),
the ribbon's route — it leaves the **centre of the RIGHT side**, legs of 4 / 20 / 10 — and
which side that is. What is left:

- [ ] **The female header row spacing** on the driver board. Not modelled. The carrier's
      mounting holes are measured now, so this only decides where the *headers* are soldered,
      not where the board sits — but it still has to match the driver's pin rows.
- [ ] **The heat-set inserts you actually have** — the model assumes M2.5, Ø3.6 bore × 5.0
      deep. Set `ins_d` / `ins_l` and re-export if yours differ.
- [ ] **The second FPC**, adapter to driver board. Length and width, and whether it exists in
      the parts box. It has no geometric constraint — routed by hand — but it wants to be long
      enough for the cover to come off and sit beside the frame, not just span the closed gap.

## 2. The adapter — solved

It is **taped to the back of the glass**, at x −40.45 … −22.45, z 65.75 … 97.75. There is
14.8 mm of depth there against the 5 it needs, it clears the driver's parts by 2.0, and leg 3's
turn falls inside its span. `adapt_board` and `adapt_cover` are both empty. No bosses, no
screws, no layout move — and taped to the glass it stays with the frame, so only the long FPC
crosses the split.

Both numbers that were gating it are measured: `adapt_env` 5.0, and leg 3 at 10 mm, which
lands on the adapter (it ends between x −35.2 and −26.2 against a footprint of −40.45 … −22.45).
The tail folds over onto the adapter and the cable on to the driver is routed by hand, so
nothing downstream is constrained. Nothing to design; two things to do at assembly:

- [ ] Use **foam** double-sided tape, not a thin film, and route the tail so its spring-back
      loads the tape in shear. Shear is ~46 N against a 0.02 N part; peel is the failure mode.
- [ ] Order the second FPC once the loop length is known — long enough for the cover to come
      off and be set down beside the frame, not just to span the closed gap.

## 3. The ribbon hollow — one small decision left

- The 18 vs 24 mm disagreement over the tail length **no longer blocks anything**: the hollow
      is sized generously at 49 mm (14.5 below the exit, 34.5 above), which covers leg 2 at
      anything from 0 to 34. Oversize costs nothing here; undersize is the only failure. Worth
      re-measuring out of curiosity, not as a gate.
- [ ] Leg 1 wants 4 mm out from the glass edge and the relief gives 3.75 — 0.25 short.
      `rib_clr = 3.25` fixes it but grows the frame 0.5 mm on the short axis. The stance no
      longer rides on the frame width, so only the frame moves. Decide whether to spend it.

## 4. Still open from the relayout

- [x] **Measure the charger breakout's mounting holes.** Done, off Adafruit's own solid model
      rather than with calipers: `fusion/vendor/adafruit-6091-bq25185-charger.step` has four
      Ø2.5 holes at (2.54, 2.54), (2.54, 22.86), (29.21, 2.54) and (29.21, 22.86) on a
      31.75 × 25.40 PCB. `chg_hx` / `chg_hz` are now **26.67 × 20.32**, up from the assumed
      25 × 19.3 — the guess came off the 32 × 26.3 *product* envelope, which includes the
      USB-C jack's overhang, and it put every post ~1 mm inboard of its hole.
- [ ] **Check the posts land on board rather than on components** on the first dry fit, and
      that the charger's Ø2.5 holes take the M2 screws with room to spare.
- [ ] **Confirm the M2 inserts you have.** The posts are bored Ø2.9 × 5.0 for a 3.2 × 4.0
      insert. Set `chg_ins_d` / `chg_ins_l` if yours differ — the post height and `chg_back`
      follow from them, and so does whether the board still clears the glass in front of it.
- [ ] Solder two 19-pin female headers to the carrier to match the driver's pin rows. The
      board's own mounting holes are now modelled (Ø2.0 at 26 × 66 centres) and the cover has
      pegs for them, so it does not need cutting to size — the adapter is taped to the glass
      and never competes with it for board area.
- [ ] The driver stack has **1.45 mm of margin** (16.0 measured against 17.45) — the carrier
      misses the stand recess entirely, so it datums to the cover's register face at 22.6
      rather than to the recess floor's backing at 18.7, less the 2.5 `carrier_lift` holds it
      off that face for its solder joints. **Confirm the 16.0 before committing to the frame**,
      and measure how far the header joints actually stand proud of the carrier's underside: if
      they need less than 2.5, dropping `carrier_lift` hands the margin straight back.

## 5. Test-print the leg (~3.2 g, ~12 min) — the whole stand is one part

Push the Ø2 × 18 rod through the printed leg (2.5 proud each side), then press that subassembly
into the cover's pocket from the back so both rod ends snap into their ears. The rod cannot go
in afterwards. Parts, print orientation and the assembly order are in the README under **The
stand subassembly**. It needs one rod and nothing else — no screws, no inserts, no clips.

**Print it with supports.** The heel's stop flat is a 35° overhang. It is the only part in the
build that needs them.

**The travel.** Walk the *whole* stroke, not just the two ends.

- [ ] The leg should swing 0° → 35° without binding anywhere.
- [ ] **Deployed, it should take a firm shove without folding.** The heel's flat is the stop;
      if the leg keeps rotating past ~35° the flat is not landing — check the print for support
      material still stuck to it before changing any parameter.
- [ ] **Measure the lean with a protractor** against the drawn 22.3° / 34.1 mm footprint. If it
      reads more upright, the heel is not reaching the floor; if it reads flatter, something is
      holding the leg off the seat.
- [ ] Folded, the leg should sit **flush with the back face** and nothing should overhang the
      bottom edge.

**Folded, nothing holds it.** The pocket has no latch and no detent, so:

- [ ] **Decide whether the leg staying shut matters.** Pick the display up, tip it forward, and
      see whether the leg swings out on its own. If it does and that is annoying in use, a lip
      across the pocket mouth is the one-line answer (`lip_h`, in git at the commit before the
      pocket was cleaned out) — but it puts a bridge back in the pocket.
- [ ] **Check the finger access actually works.** Off the ears there is 2.5 open either side of
      the leg, the whole length, at the full 4.5 depth. If a nail won't go under the leg's edge,
      the pocket has to get wider — but `rec_w` is capped at ~18.9 by the driver carrier at
      x −11.45, and widening it also widens `leg_w`'s derivation.
- [ ] **Hold the cover up to the light before assembling.** The pocket must be blind everywhere:
      no daylight through its floor, none through either **end wall** (the step at z 11.3 and
      the far end at z 63.5 — that pair was open into the electronics bay until the boss was
      made to overrun the pocket), and the two ears solid with their C-mouths open into the
      pocket, not through the back face. `chk="rec_floor_gap"` covers all of it in the model,
      but a thin wall can still print through.
- [ ] **Check the bottom of the pocket once frame and cover are screwed together.** The floor
      plate stops 1.15 mm clear of the rear chamfer so its fit gap cannot surface there — look
      along the bottom edge and there should be no slot into the frame. The model is sealed
      (`POCKET FLOOR PLATE` echo); what a print does with a 0.15 mm fit gap and a 1.15 mm
      ledge is the thing to confirm. Behind that plate the frame is now solid, so even a bad
      print there opens into material rather than into the case.

**The pin socket.** This is the one feature that could fail on the first assembly:

- [ ] The rod should **snap past the socket mouth** (1.51 across a 2.1 bore) and then be
      retained. If the lip shears instead of flexing, raise `ear_mouth` toward 0.8 so there is
      less to deflect, and check the cover printed the mouth open rather than bridged over.
- [ ] **This is the only way the rod goes in.** Nothing can be threaded along the pivot axis
      from inside the cover: at depth 23.0 the register plate fills the depth either side of
      the recess boss, so there is no straight run for an 18 mm rod. Tension from the back
      face is the route, which is why the sockets keep their C-mouths.

**After a few dozen cycles:**

- [ ] Check the pin and its two sockets for wear — they are the only sliding contact left in
      the stand.
- [ ] Check the heel's contact patch. It is a 3.07 × 14 face, so bearing stress is negligible;
      if it is visibly rounding over, the flat is not seating square.

## 5b. Fridge magnets

`mag_fit = false`: the discs are **glued onto** the back face, not sunk into it. The pigtail
flange stands 2.00 mm proud and is the rearmost thing on the case, so a sunk disc sat 2.2 mm
off the door and gripped nothing; a 2 mm disc on the surface is exactly as proud as the flange
and reaches the steel. The positions are still derived and still printed by the `FRIDGE
MAGNETS` echo — glue to those, not by eye.

- [ ] **Test the fridge door with any magnet.** A lot of "stainless" doors are austenitic and
      hold nothing at all.
- [ ] **Mark x ±27.6 before gluing** — z 83.65 on the +X side, z 92.1 on the −X side. Equal x
      is the whole rule: it puts the pair's centroid on the centreline. Offset, it hangs
      crooked. Re-read the echo first if you changed `mag_d`, because `mag_x` moves with it.
- [ ] **Measure the discs you actually have.** The model assumes Ø8 × 2. `mag_t` is what makes
      the surface mount work — a disc thinner than the flange's 2.00 mm will not reach the
      door, and the fix for that is a spacer under it, not a thinner flange.
- [ ] **Glue with epoxy, not CA.** A surface-glued disc is held by the bond alone, and CA is
      brittle in peel — which is the load a disc sees when you pull the case off the door.
      Scuff both faces, and let it cure before hanging anything on it.
- [ ] **Hang it and leave it a week before trusting it.** ~3.3x shear margin is calculated, not
      measured. If the door is thin-skinned and it slips, the fix is bigger discs — check the
      echo's positions again afterwards, because both move with `mag_d`.

## 6. Print and check the bezel test tile before the frame

- [ ] Print `stl/bezel_test.stl`, front face down (~40 min, ~20 g).
- [ ] Drop the real module in. Check: glass seats in the 77.5 × 91.5 pocket, all four
      pocket corners clear on their R1.4 relief, the window lip sits flush, and the
      **ribbon folds back through the 49 mm hollow without strain** — 3 mm out from the
      pocket edge and 3 mm past the glass back face. The hollow straddles the **centre of
      the RIGHT side** and runs towards the TOP (30.5 up from the BOTTOM, 49 long, 10.5
      short of the TOP). Check the side and the position before anything else — both were
      wrong until 2026-08-25, and the hollow is deliberately oversized because too big
      costs nothing and too small does not.
- [ ] Check the white border shows evenly: 0.7 mm on the short axis, 1.3 mm on the long.
      Lopsided means `act_off_x` (3.2, derived from the measured 3.0 / 9.4 borders) is off.
- [ ] Melt four **M2.5** inserts into the frame's corner bores, flush with the mating face,
      and check the countersunk heads finish level with the back face.

## 7. Electrical assembly

- [ ] Set the bq25185's charge current to **1 A** with the solder jumper. Adafruit's
      product page and pinout guide disagree on the default (1 A vs 500 mA) — read the
      board, don't assume.
- [ ] **Cut the TH jumper** and wire the cell's yellow lead to the **TH** pad. The pack's
      NTC is confirmed (10 kΩ yellow→black at room temperature), so the charger should be
      using it: it then refuses to charge outside roughly 0–45 °C.
- [ ] Wire red → B+, black → B− on the JST battery pigtail (polarity verified on this
      pack).
- [ ] Wire the USB-C pigtail's **VBUS** and **GND** to the charger's VBUS and GND pads.
      Confirm the pigtail has the 5.1 kΩ CC1/CC2 pulldowns, or no USB-C source will turn
      its 5 V on. The port now sits at x −5, z 92, immediately left of the charger, so this
      is a ~4 mm run — leave a little slack so the cover can still lift off.
- [ ] Build the battery divider: 100 kΩ from cell + to **GPIO 35**, 100 kΩ from that
      same tap to the driver board's GND. Full wiring and why GPIO 35 is in the README's
      "Wiring the battery sense". The firmware already reads it; until it is fitted the
      pin floats and Home Assistant shows ~0 V.
- [ ] Once the divider reads true, add the low-voltage cutoff (~3.6 V, sleep with no wake
      source). Left out on purpose while the pin floats — a floating read looks like a
      flat cell, and that path has no way back inside a sealed case.
- [ ] **Flash the ESP32 and confirm OTA works before the cover goes on.** The flash port
      is closed (`flash_port = false`) and the charge port is deliberately two wires, no
      data — after assembly there is no wired route in.
- [ ] Set the **DIP switch so the USB-UART is unpowered** when running (on only to
      program). Left powered, idle draw goes from ~2 mA to 10–13 mA. On the Rev 3 board
      that chip is a CH343, not the CP2102 the older product page quotes.
- [ ] Use **GPIO 4's panel-rail gate**: the schematic has it driving an S8050 that switches
      VDD5V → VDD5V′, so firmware can drop the panel supply in sleep. Keep GPIO 4 off the
      button list.

## 8. Firmware

- [ ] Read the divider on **every** wake. Below ~3.6 V, call `esp_deep_sleep_start()` with
      no timer and stay there. The board browns out at 3.6 V on its own, but a brownout
      loop drags the cell to its protection cut, and deep discharge is what kills cells.
- [ ] Show state of charge from the same reading, and stop refreshing when the cell is low.

## 9. Measurements worth taking once it runs

- [ ] Put a multimeter **in series with the battery lead** and read the real sleep current.
      Waveshare's `<2 mA` is a spec, not this board, and a USB meter won't resolve single
      milliamps. Everything in the runtime estimate hangs off this number.
- [ ] If there's a power LED on the driver board, measure what cutting it saves — often
      1–2 mA.

## 10. Optional, not started

- [ ] Three side buttons: `btn_n = 3`, then `btn_d` / `btn_sp`, and re-export the frame.

## 11. Housekeeping

- [ ] `drawings/4.2in-frame-drawings.pdf` is stale — it predates the current sheets. It was
      printed from `drawings/index.html`, so regenerate it the same way (or drop it and
      treat the SVG sheets plus `index.html` as the only drawing deliverables).
- [ ] `slicer/assembly-test.3mf` and `slicer/leg-test.3mf` predate the stand redesign — they
      were saved from an older set of STLs (including the deleted `disc.stl`) and will open
      with stale geometry. Re-save them from the current exports or drop them.
- [ ] `src/` still carries `epaper_stand_v2/v3/v4.scad` alongside the live
      `epaper_stand.scad`. Decide which are worth keeping and move the rest next to
      `archive-v1-wedge/`.
</content>

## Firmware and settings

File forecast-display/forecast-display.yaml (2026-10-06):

# Adapted from https://github.com/Madelena/esphome-weatherman-dashboard
# And https://blog.wijman.net/e-ink-weather-frame-with-esphome-and-home-assistant/
# With a lot of my own additions, fixes, edits. My github: https://github.com/trip5

substitutions:
  name: eink-weatherboard
  friendly_name: eInk-WeatherBoard
  project_name: "Trip5.eInk-WeatherBoard"
  comment: "eInk-WeatherBoard from Trip5"
  project_version: "2024.11.28"
  time_zone: "America/New_York" # Check https://en.wikipedia.org/wiki/List_of_tz_database_time_zones
  adc_pin: GPIO14 # ADC2, which WiFi takes over: read at boot, before WiFi starts
  adc_gpio: '14'
  sleep_time: 60min # this is the default but is overridden
  max_run_time: 3min # failsafe: the longest a wake can last before it sleeps for ${sleep_time} anyway (e.g. WiFi or Home Assistant down). The Disable Deep Sleep helper overrides it.

# Home Assistant entitites:
  ha_disable_update: input_boolean.eink_weatherboard_disable_update
  ha_disable_deep_sleep: input_boolean.eink_weatherboard_disable_deep_sleep
  ha_weather_data: sensor.eink_weatherboard_data
  ha_wake_times: sensor.eink_weatherboard_wake_times
 
# A physical switch to disable deep sleep (optional, if no physical switch is attached then no problem)
  deep_sleep_disable_pin: GPIO21

# Waveshare eInk Board:
# Using lilygo boards, I don't think we need this
  # status_led_pin: GPIO2 # Don't think we have access to the led pin
  # mosi_pin: GPIO15
  # clk_pin: GPIO12
  # cs_pin: GPIO42
  # dc_pin: GPIO27
  # reset_pin: GPIO26
  # busy_pin: GPIO25
  # busy_inverted: "True" #needed on most newer boards: check ESPHome or component notes

  # Everything here is meant for an 7.5 inch tricolor display, which is (as of 2024.12.0) now directly supported by ESPHome (thanks, JonasB2497!)
  # See here for full list of directly-supported displays: https://esphome.io/components/display/waveshare_epaper.html
  # if using only BW, then you may need to edit colors below (change red to same as black)
  # model: 7.50in-bv3-bwr

esphome:
  name: ${name}
  comment: "${comment}"
  project:
    name: "${project_name}"
    version: "${project_version}"
  on_boot:
    # Battery first, before WiFi starts (WiFi sets up at priority 250). GPIO14
    # is on ADC2, which the radio takes over once it is up, so this is the one
    # point in a wake where it can be read without dropping the connection.
    - priority: 600
      then:
        - lambda: |-
            // Read the raw ADC value (0-4095, proportional to the pin voltage)
            int raw_value = analogRead(${adc_gpio});
            // Reference voltage for the ADC (typically 3.3V for ESP32)
            float V_ref = 3.3;
            float V_adc = ((float) raw_value / 4095.0) * V_ref;
            // Divider factor from your voltage divider.
            // For example, many Lilygo T5 boards have a divider factor around 1.84.
            float divider_factor = 1.84;
            float battery_voltage = V_adc * divider_factor;
            // Trim battery voltage to two decimals:
            battery_voltage = round(battery_voltage * 100.0) / 100.0;
            id(battery_voltage_global) = battery_voltage;
            ESP_LOGI("battery", "Raw ADC: %d, ADC Voltage: %.2f V, Battery Voltage: %.2f V", raw_value, V_adc, battery_voltage);
    - priority: -100.0
      then:
        # - lambda: 'id(recorded_display_refresh) = 1488;' # if you need to manually update the number of refreshes (flash once with a set value then comment the line and reflash again)
        # - script.execute: led_blink
        - wait_until:
            condition: api.connected
        - component.update: battery_voltage # this wake's reading, not the last one
        - if:
            condition:
              or:
                - binary_sensor.is_on: deep_sleep_disable_ha # checks Home Assistant Helper
            then:
              - script.execute: deep_sleep_evaluation
            else:
              - script.execute: get_data_then_refresh_screen
  # Runs on every deep sleep. The t547 driver ends each refresh with
  # epd_poweroff(), which leaves the panel's control register partly set;
  # LilyGo's own sleep example clears all of it with epd_poweroff_all()
  # before esp_deep_sleep_start().
  on_shutdown:
    - lambda: 'epd_poweroff_all();'
  libraries:
    - SPI
    - Wire # the t547 component's touch.h includes it; newer ESPHome no longer links it by default
  area: Master Bedroom
  # build_path: /config/esphome/.esphome/forecast-display/

esp32:
  board: esp32-s3-devkitc-1
  # The board has 16MB, but the installed partition table is the 4MB layout,
  # and OTA cannot rewrite a partition table. Moving to 16MB takes one USB flash.
  flash_size: 4MB
  cpu_frequency: 240MHz
  framework:
    type: arduino

# The panel's framebuffer lives in PSRAM (8MB octal on this board).
psram:
  mode: octal
  speed: 80MHz
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

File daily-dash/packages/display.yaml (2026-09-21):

# ============================================================================
# DISPLAY -- the panel, the fonts, and everything that draws
# ============================================================================
# Waveshare 4.2in e-Paper (B) V2 (400x300 black/white/red) on the Waveshare
# e-Paper ESP32 Driver Board. Rotated 270 deg, so the drawing canvas is
# 300 wide x 400 tall (PORTRAIT).
#
# Driver: https://github.com/astoker/esphome-waveshare-4in2b-v2
#   ESPHome's built-in 4.20in-bV2-bwr only drives the OLD panel revision.
#   This component auto-detects OLD (0x10/0x13, busy LOW) vs NEW (0x24/0x26,
#   busy HIGH) at boot -- no busy_pin inversion or reset_duration override.
#
# The panel is full-refresh only (~16-17 s) and redraws once per wake at most.
#
# ONE LAMBDA, THREE SCREENS, chosen by render_mode:
#   0  the agenda          (below)
#   1  Home Assistant is unreachable
#   2  a picture           (streamed by packages/image.yaml)
#
# ----------------------------------------------------------------------------
# THE AGENDA SCREEN: AN HOUR RULER
# ----------------------------------------------------------------------------
#   22  TUESDAY              <- header is side-by-side: 62 px instead of 176
#       September 2026
#   ------------------------
#   # Trash night            <- all-day items, pinned above the ruler
#   ------------------------
#  >2 |Customer call         <- the CURRENT hour is always the top band, and
#   pm :30                      the red wedge in the margin is the minute
#   3  ---------------------
#   4  ---------------------
#   5  Soccer pickup
#   6  ---------------------
#   7  Dinner at Mom's
#   ------------------------
#   LATER TODAY
#    8p  Book club           <- whatever the ruler could not reach, in full
#   9:30p Take the trash out
#   ------------------------                        2:50 pm
#
# THE PANEL SHOWS THE FUTURE. An event whose end time has passed is dropped
# entirely, so the top of the ruler walks down the day on its own and the
# space is spent on what is still ahead. All-day events are the exception:
# they sit above the ruler until midnight, because they have no place on a
# time axis and stay useful all day.
#
# AN EVENT STILL RUNNING IS CARRIED into the current band. A 12:30 lunch seen
# at 1:15 has an hour that is already off the top of the ruler, so it is drawn
# in the 1 pm band and labelled "til 1:30" -- a ":30" there would read as the
# wrong hour. The current hour is the anchor of the layout and is the one band
# the collapse never absorbs.
#
# EMPTY HOURS ARE KEPT, at ${ruler_empty_h} px, so a two-hour gap looks like a
# gap. A run of three or more empty hours collapses to a three-dot marker, but
# only when the day would otherwise overflow -- and when the whole day does
# fit, the leftover height is spread across the empty bands so the ruler
# reaches the footer.
#
# THE RULER RUNS at least four hours past the current one, so a lone 7pm
# dinner still fills the panel.
#
# NOTHING IS EVER REPLACED BY A COUNT. The hour view takes as many bands as
# will fit above a COMPLETE list of everything it leaves out, so the panel
# always names every event still ahead. A packed morning gets fewer hours and
# more list rows; the hours come back on their own as the day empties. The
# list has two type tiers (16 px and 13 px rows) and, past those, shrinks its
# row pitch to whatever divides the space.
#
# RED carries the date, the month, the current hour's rule and numeral, the
# now-wedge, the live event, the all-day bullets and the tail's label.
#
# Previewing: tools/preview/render.py draws this layout to PNG on the same
# 300 x 400 canvas with the same 1-bit type, at any time of day and against
# several sample agendas. Iterate there, then port here.
#
# Pins, rotation, the font family and the ruler's geometry are substitutions
# in packages/defaults.yaml.
#
# Defines: epaper_display, render_mode, the fonts.
# Consumes: agenda_json, display_mode, blob_fetcher, sys_time, api_fail_streak.
# ============================================================================

globals:
  # What the display lambda should draw: 0 = the agenda, 1 = the dog.
  - id: render_mode
    type: int
    restore_value: false
    initial_value: '0'
  # Per-boot, so restore_value stays false: the cold-boot window is offered
  # once per power-up, not once per wake.
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

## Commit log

2026-08-24 bezel set up
    [bezel_test.stl, cover.stl, disc.stl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]
2026-08-24 baby steps
    [epaper_stand.scad, mkrenders.scad]
2026-08-24 mid thinking
    [bezel_test.stl, cover.stl, disc.stl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]
2026-08-27 pre-fusion conversion
    [bezel_test.stl, cover.stl, disc.stl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]
2026-09-14 some updates
    [cavity.dxf, cover.3mf, cover.stl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]
2026-09-14 trying to close a gap
    [assembly-test.3mf, bezel_test.stl, cavity.dxf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]
2026-09-14 fixing holes
    [assembly-test.3mf, bezel_test.stl, cavity.dxf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]
2026-09-16 stand changes
    [assembly-test.3mf, cover.3mf, cover.stl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]
2026-09-18 hardware and yaml
    [cover.3mf, cover.stl, cover_in.dxf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]
2026-11-08 RÖDALM 4x6 frame insert for the daily dash
    Move the 4.2" panel from the printed stand into an IKEA RÖDALM 4x6 frame.
    build123d model (src/rodalm_frame.py) for a printed mat that carries the
    glass, a cassette that holds every board, a lid, and an easel strut, plus
    fit coupons and an insert gauge. 3MF print files, STEP for Fusion, renders,
    and the power / battery-sense / USB-present wiring schematic.
    Frame measured: rebate 100 x 150, sight 85 x 135, inside depth 25, tabs at
    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
2026-11-08 RÖDALM: wider strut, one OrcaSlicer project for every part
    - Strut flares from 24 mm at the hinge to 44 mm at the foot for
    side-to-side support; the pin is now 2 x 30.8 mm. Lid ears move with it.
    - 3mf/rodalm-frame.3mf replaces the seven single-part 3MFs: one OrcaSlicer
    project, three named plates (mat + lid on the smooth sheet, cassette +
    strut, fit test), opening with the AD5M Pro presets copied from the
    stand's projects into slicer/orca_project_settings.config.
    - Mat and cassette are unchanged.
    Claude-Session: https://claude.ai/code/session_01Gzk3HrsDB3G7ZruGooakeJ
2026-11-08 RÖDALM: strut folds flush into the lid; USB-C flange recessed
    The back is now flat with the strut folded, so the frame can hang on a
    wall from the keyholes.
    - The strut folds into a pocket in the lid and turns on a captive 2 mm
    rod (30.8 long, same as before) through two hinge walls. The pocket
    is a tub under the lid that misses the driver, tab wells and bosses,
    so the strut is off centre: 24 wide at the hinge (X -5..19), 37.5 at
    the foot (X 0.5..38), 126.9 long. A finger scoop beside the foot lifts
    it out.
    - A strut that fits inside the frame can't reach a 20 deg lean: the
    flattest is 27.8. The swing is now solved as the largest within 0.5
    deg of that (34.5 deg -> 28.3 lean,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
